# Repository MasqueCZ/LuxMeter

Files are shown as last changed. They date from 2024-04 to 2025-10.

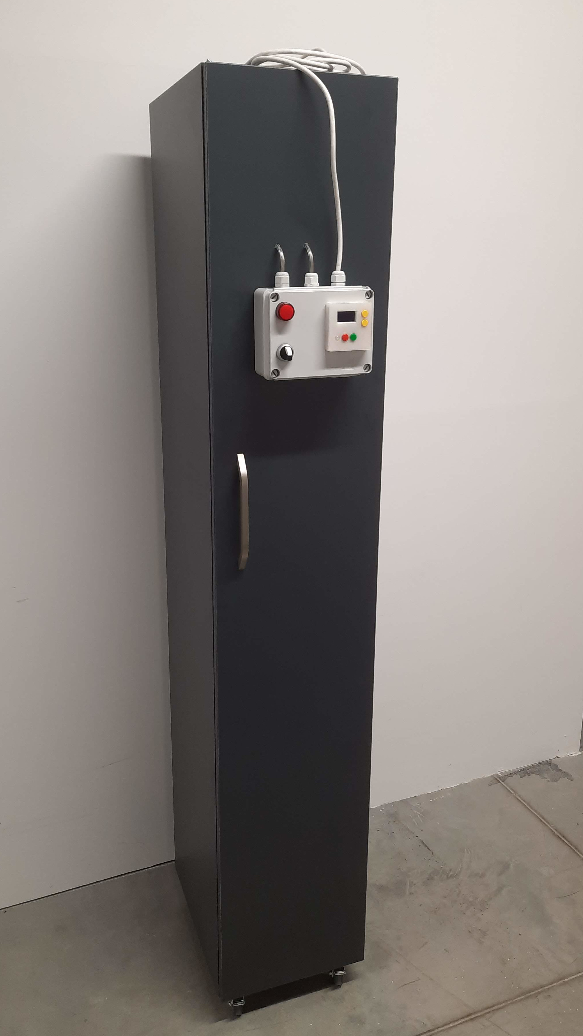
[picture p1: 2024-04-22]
HELPMEfile - MANUAL/Fotky/20240103_172350.jpg

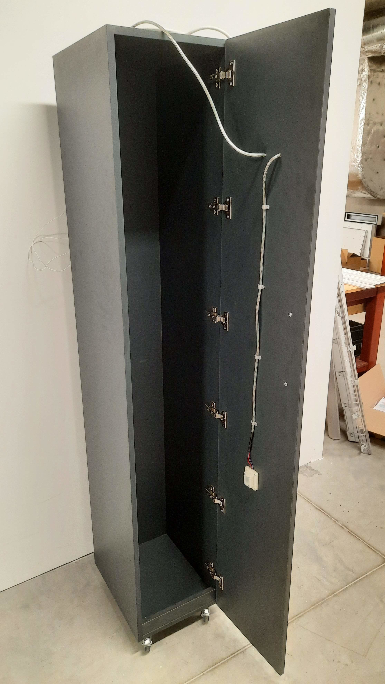
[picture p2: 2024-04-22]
HELPMEfile - MANUAL/Fotky/20240103_172510.jpg

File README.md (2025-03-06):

# LuxMeter
microPython - RPiPico LuxMeter with RTC and SSR relay

My first project, be gentle with comments, but I am open to improvements.

Main part of the project was to measure lumen(light) data over time, save them and then use spreadsheets to analyze the result.
But as clever workers are expensive, I was forced to make different programs, which are tailor made just for one type of 
luminaire and at the end of the measurement, you have result in GREEN or RED light and small text file with important 
milestones of corridor function. (for more detailed info about corridor function see blueprints/scheme.jpg)

But as universal measurement was the main pillar of the project, it is updated the most. And it is now in the list of 
programs under name 00_uni_uni.py.

# uni_uni
You can select sampling time from values 1, 5, 10, 30, 60, 600 and 3600 seconds and the measurement can end at selected 
time of 0, 1, 2, 4, 8, 12, 24, 168 hours. It measures indefinitely if zero is selected.

There is data saver feature which stops saving data after 2 same measurements the 3rd is just "stable" and it continues 
to measure but does not take up another space unless the value changes.

There is also a SSR relay that turns on the power at the start of the measurement, second relay can be turned temporarily
by pushing buttons UP and DOWN at the same time. It can be used to re-start the corridor function cycle or jumpstart
emergency mode for certain luminaires, etc.

-work in progress-

1 - I work on 2 level stable checker, one without a tolerance, one with tolerance but I have to polish it since it can 
slowly slide out of tolerance, without the program realising, since it is so slow, changes, that they would be then 
seen as STABLE.

2 - I want to add data write, even if stable and within the tolerance to save data at least once a minute or once a hour 
or a day, if the sampling is lower, then battery dying or power outage could ruin measurement,
even though it already measured for certain time, but the value never changed it is not written to the file, then you never know when it actually stopped.

3 - Keep all notes in English and translate and then delete czech notes and comments

4 - add magnetic sensor to enter special mode?

5 - menu, while choosing a program, if continuous push of a button scroll faster? Jump by 2, 5 or faster?

6 - add memory check at start so it does not begin if there is not enough space to save file??

7 - make .mpy compiled and compressed files to save 40-60% space?

8 - config file in json? instead of .py?

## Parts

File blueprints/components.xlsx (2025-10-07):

Cena komponent | 610 Kč |  |  | + nějaký box - nově bych netiskl celou krabici, ale použil "skladovku" od ABB, elektrikářský box a tiskl menší část jen pro displej a tlačítko.
alternativně | 1051 Kč |  |  | (nemám pořešený software pro displej s jiným řízením, enkodér (otočný knoflík už trochu jo))
KOMPONENTY
Raspberry Pi Pico | 119 Kč | 1 | 119 Kč | https://rpishop.cz/pico/5117-raspberry-pi-pico-0617588405587.html
IIC I2C OLED displej 0,96" 128x64 Bílý | 115 Kč | 1 | 115 Kč | https://dratek.cz/arduino/1569-iic-i2c-oled-display-0-96-128x64-bily.html
Měření intenzity světla BH1750 | 57 Kč | 1 | 57 Kč | https://dratek.cz/arduino/902-mereni-intenzity-svetla-bh1750.html
RTC hodiny reálného času | 61 Kč | 1 | 61 Kč | https://dratek.cz/arduino/842-rtc-hodiny-realneho-casu.html
CR2032 baterie | 20 Kč | 1 | 20 Kč | https://dratek.cz/arduino/1538-lithiova-knoflikova-baterie-westinghouse-cr2032-dl2032-5004lc-e-cr2032-3v.html
Nepájivé pole 400 pinů | 45 Kč | 1 | 45 Kč | https://dratek.cz/arduino/1226-eses-nepajive-pole-400-pinu.html
40 x M-M Dupont kabel, 20 cm | 53 Kč | 1 | 53 Kč | https://dratek.cz/arduino/1063-eses-40-x-m-m-dupont-kabel.html
40 x M-F Dupont kabel 20 cm | 53 Kč | 1 | 53 Kč | https://dratek.cz/arduino/1214-40-x-m-f-dupont-kabel-20-cm.html
RGB LED modul WS2811 | 15 Kč | 1 | 15 Kč | https://dratek.cz/arduino/1192-rgb-led-modul-ws2811.html
SSR Relé Modul 1 kanál 5VDC Low Level | 53 Kč | 1 | 53 Kč | https://dratek.cz/arduino/1346-ssr-rele-modul-1-kanal-5vdc-250vac-omron-g3mb-202p-solid-state-pro-arduino.html
DuPont kolíková lišta rovná 40Pin samec černá | 3 Kč | 1 | 3 Kč | https://dratek.cz/arduino/1331-dupont-40pin-2-54-mm-kolikova-lista-rovna.html
Mikrospínač TC-1212T 12x12x7.3mm SMD PCB DPS | 4 Kč | 4 | 16 Kč | https://dratek.cz/arduino/1180-mikrospinac-tc-1212t-12x12x7.3mm-smd-pcb-dps.html
SSR Relé Modul 2 kanál 5VDC Low Level | 76 Kč | 1 | 76 Kč | https://dratek.cz/arduino/1347-ssr-rele-modul-2-kanaly-5vdc-250vac-omron-g3mb-202p-solid-state-pro-arduino.html
alternativní komponenty na další verze
Mikrospínač TC-1212T 12x12x7.3mm SMD PCB DPS | 4 Kč | 1 | 4 Kč | duplicitně
Rotační enkodér KY-040 s tlačítkem | 36 Kč | 1 | 36 Kč | https://rpishop.cz/tlacitka-spinace/1329-rotacni-enkoder-ky-040-s-tlacitkem.html
SPI OLED displej 1,54" 128x64 Modrý 3,3-5V | 349 Kč | 1 | 349 Kč | https://dratek.cz/arduino/121930-spi-oled-displej-1-54-128x64-modry-3-3-5v.html
SPI Čtečka microSD karet | 24 Kč | 1 | 24 Kč | https://dratek.cz/arduino/993-ctecka-microsd-karet.html
paměťová karta 16 GB již od | 159 Kč | 1 | 159 Kč
 |  | 2 |  | https://dratek.cz/arduino/121748-40-x-m-m-dupont-kabel-40-cm.html
 |  | 2 |  | https://dratek.cz/arduino/121747-40-x-m-f-dupont-kabel-40-cm.html
 |  | 1 |  | https://rpishop.cz/pico/5117-raspberry-pi-pico-0617588405587.html
 |  | ? |  | https://dratek.cz/arduino/121930-spi-oled-displej-1-54-128x64-modry-3-3-5v.html
 |  | 2 |  | https://dratek.cz/arduino/1347-ssr-rele-modul-2-kanaly-5vdc-250vac-omron-g3mb-202p-solid-state-pro-arduino.html
 |  | 2 |  | https://rpishop.cz/tlacitka-spinace/1329-rotacni-enkoder-ky-040-s-tlacitkem.html
 |  | 2 |  | https://dratek.cz/arduino/993-ctecka-microsd-karet.html
 |  | ? | 167 Kč | https://dratek.cz/arduino/122152-iic-i2c-oled-1-3-displej-128x64-modry.html
 |  | 1 | 350 | https://dratek.cz/arduino/7545-cinova-pajka-bezolovnata-100g-sn99-3cu0-7.html
 |  | 1 | 27 | https://dratek.cz/arduino/1223-analogovy-multiplexer-16-kanalu-cd74hc4067.html
 |  | 9 | 67 | https://dratek.cz/arduino/902-mereni-intenzity-svetla-bh1750.html
SSR Relé Modul 2 kanál 5VDC Low Level | 76 Kč | 3 | 228 Kč | https://dratek.cz/arduino/1347-ssr-rele-modul-2-kanaly-5vdc-250vac-omron-g3mb-202p-solid-state-pro-arduino.html
Raspberry Pi Pico 2 W | 209 Kč | 10 | 2090 Kč | https://rpishop.cz/554053/raspberry-pi-pico-2-w
odpor 33k
odpor 10k

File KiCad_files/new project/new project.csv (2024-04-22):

Source: | C:\Users\novak\PycharmProjects\pythonProject_LuxMeter\KiCad_files\new project\new project.kicad_sch
Date: | 24/02/2023 08:26:35
Tool: | Eeschema (7.0.0)
Generator: | C:\Program Files\KiCad\7.0\bin\scripting\plugins/bom_csv_grouped_by_value_with_fp.py
Component Count: | 4
Ref | Qnty | Value | Cmp name | Footprint | Description | Vendor | DNP
D1 | 1 | SMF30A | SMF30A | Diode_SMD:D_SMF | 200W unidirectional Transil Transient Voltage Suppressor, 30Vrwm, SMF
D2 | 1 | 1.5KExxA | 1.5KExxA | Diode_THT:D_DO-201AE_P15.24mm_Horizontal | 1500W unidirectional TRANSZORB® Transient Voltage Suppressor, DO-201AE
SW1 | 1 | SW_DIP_x04 | SW_DIP_x04 |  | 4x DIP Switch, Single Pole Single Throw (SPST) switch, small symbol
U1 | 1 | RP2040 | RP2040 | Package_DFN_QFN:QFN-56-1EP_7x7mm_P0.4mm_EP3.2x3.2mm | A microcontroller by Raspberry Pi

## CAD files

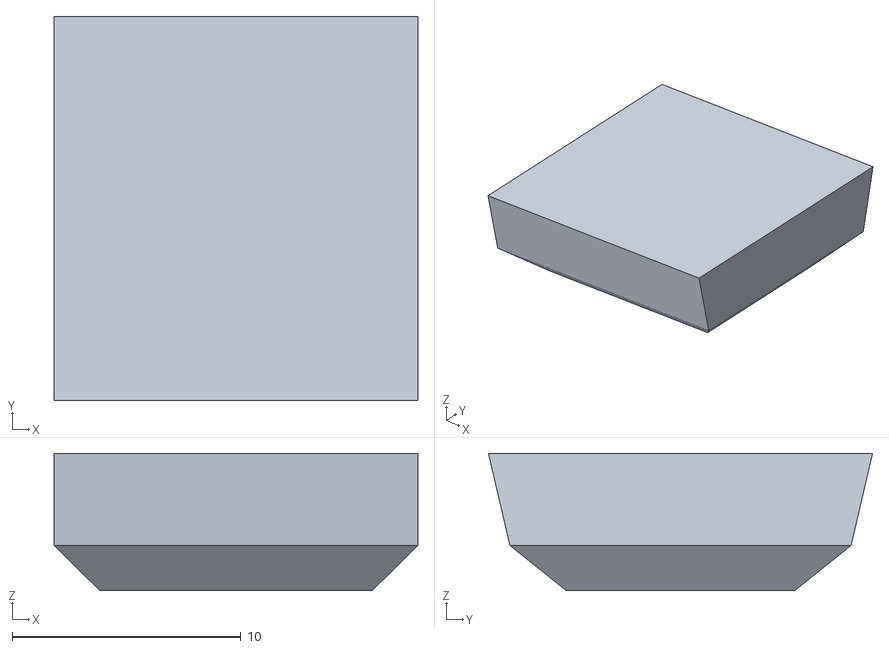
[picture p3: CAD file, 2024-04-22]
3DPRINT/WINDOW-door V0.2.stl
15.9 x 16.8 x 6.00

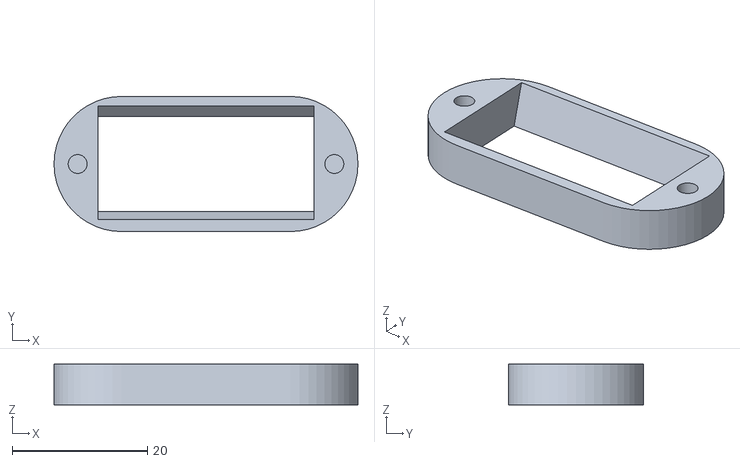
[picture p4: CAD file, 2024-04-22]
3DPRINT/WINDOW V0.2.stl
45.0 x 20.0 x 6.00

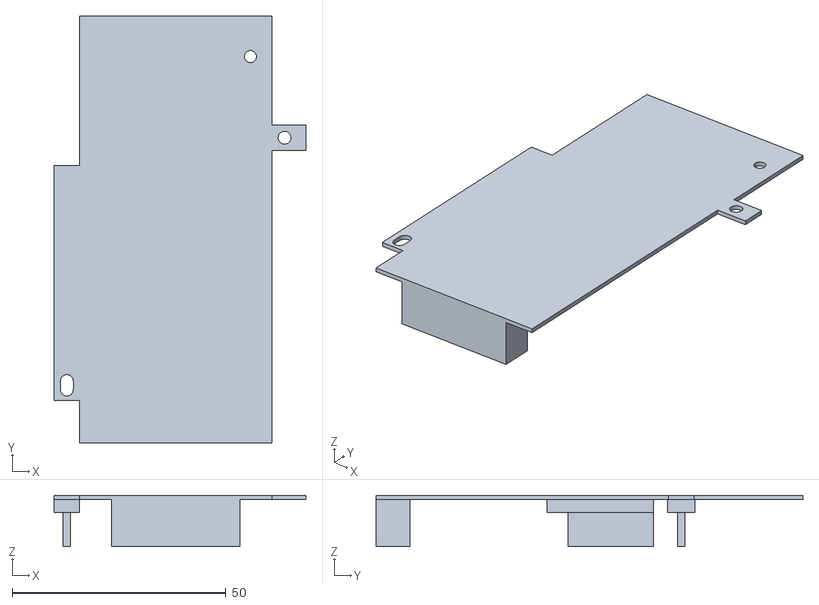
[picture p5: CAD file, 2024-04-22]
3DPRINT/BREADBOARD BED.stl
59.0 x 100.0 x 12.0

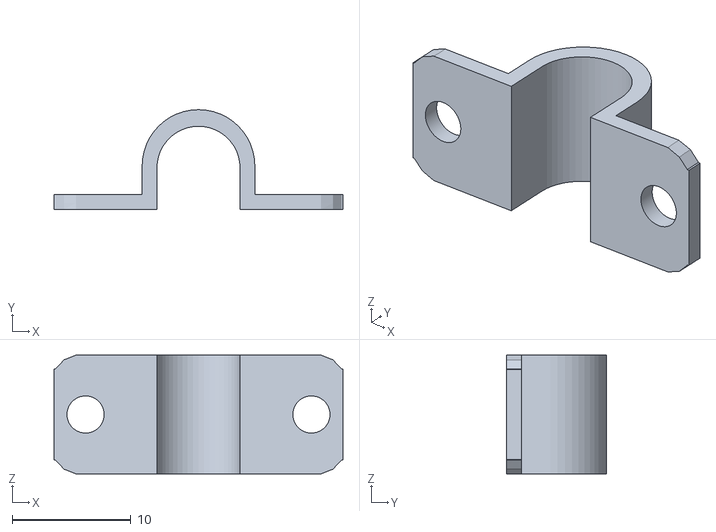
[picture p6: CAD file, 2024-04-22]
3DPRINT/drzak kabelu1.stl
24.4 x 8.41 x 10.0

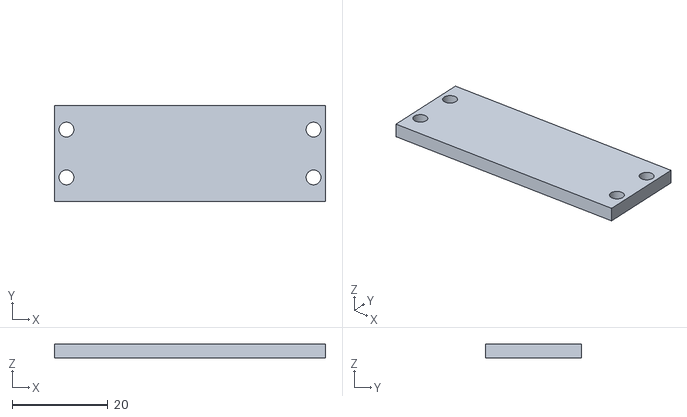
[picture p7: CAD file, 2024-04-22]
3DPRINT/BUTT HOLDER.stl
56.7 x 20.0 x 3.00

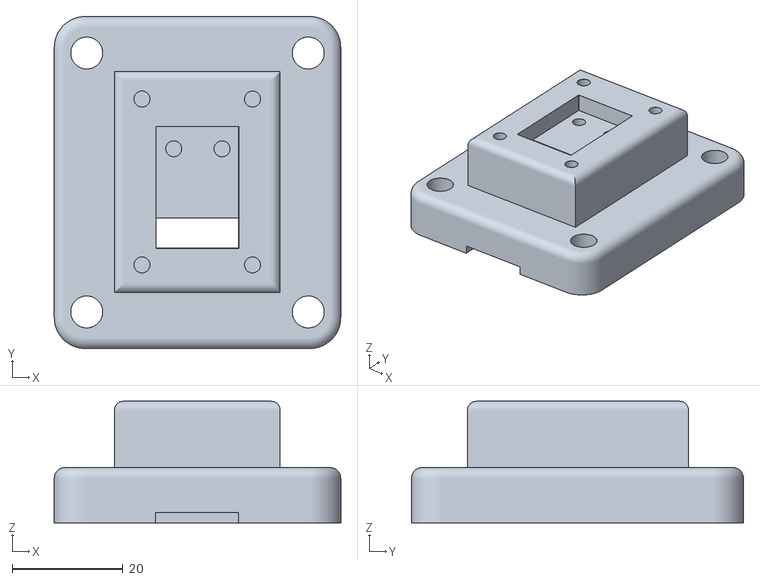
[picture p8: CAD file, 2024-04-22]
3DPRINT/2022_04_26_LUX METER BOX SNS case V.XYZ01.stl
51.8 x 60.1 x 22.0

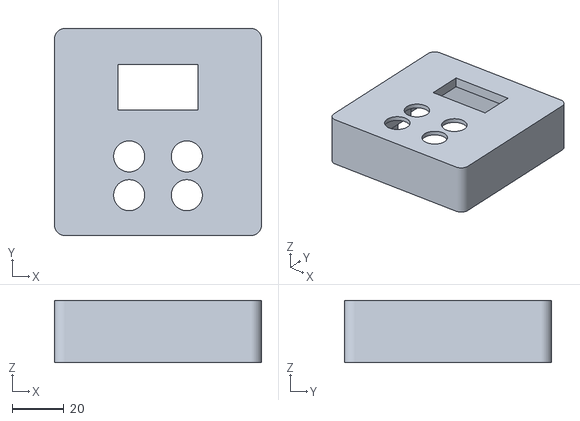
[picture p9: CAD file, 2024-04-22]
3DPRINT/DSP 1.3 and new buttons v04.stl
80.0 x 80.0 x 24.0

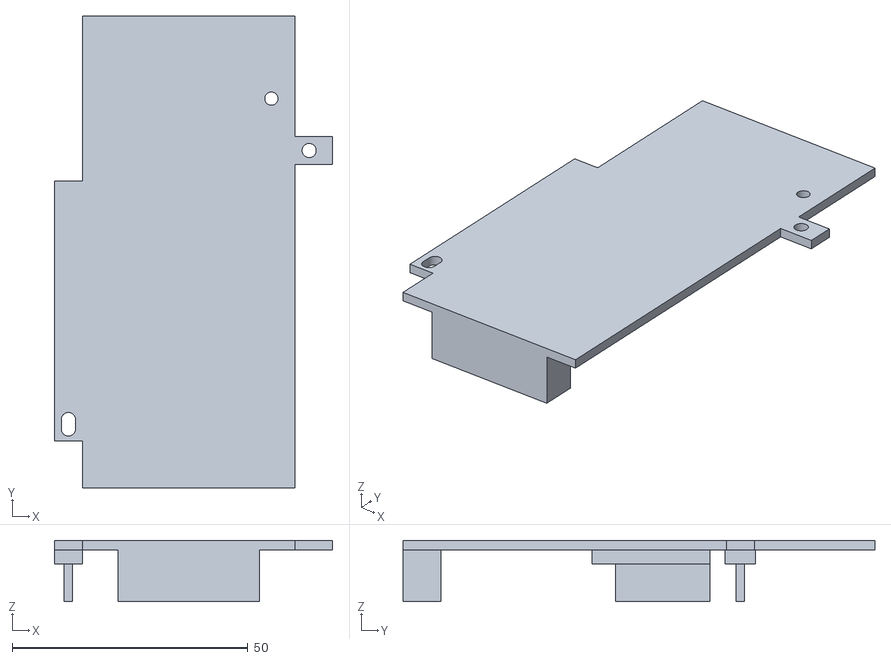
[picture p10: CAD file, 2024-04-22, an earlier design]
3DPRINT/old/test-test-basic box - breadboard BED V0.2.stl
59.0 x 100.0 x 13.0

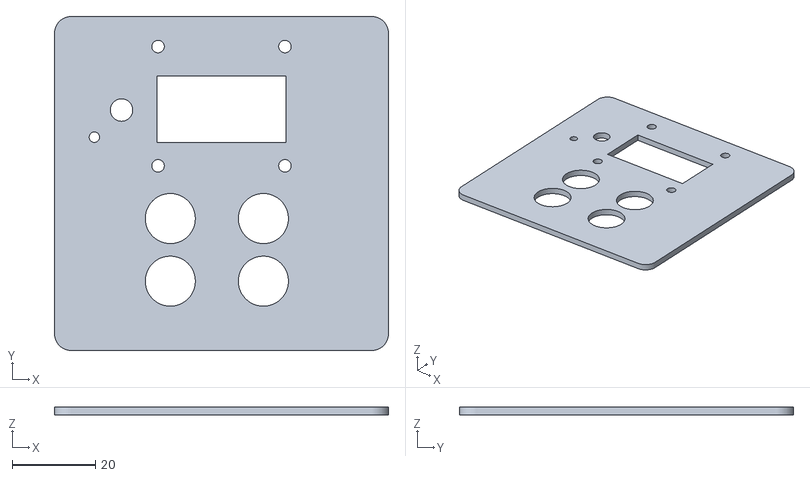
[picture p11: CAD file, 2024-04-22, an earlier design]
3DPRINT/old/test pro novou 1.stl
80.0 x 80.0 x 2.00

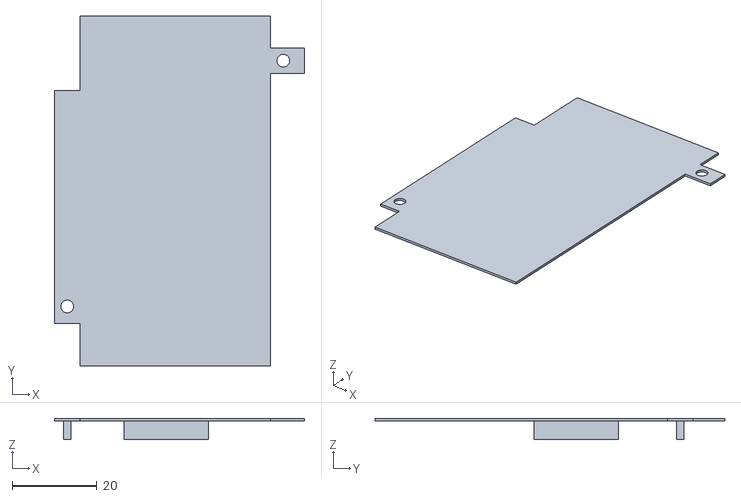
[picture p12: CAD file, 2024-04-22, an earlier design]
3DPRINT/old/test-test-basic box - breadboard BED V0.1.stl
59.0 x 82.5 x 5.00

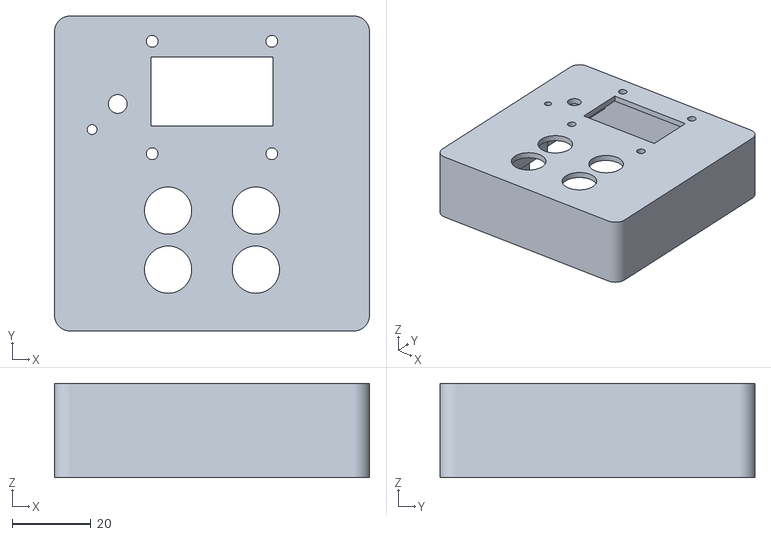
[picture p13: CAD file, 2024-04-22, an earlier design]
3DPRINT/old/test pro novou 3.stl
80.0 x 80.0 x 24.0

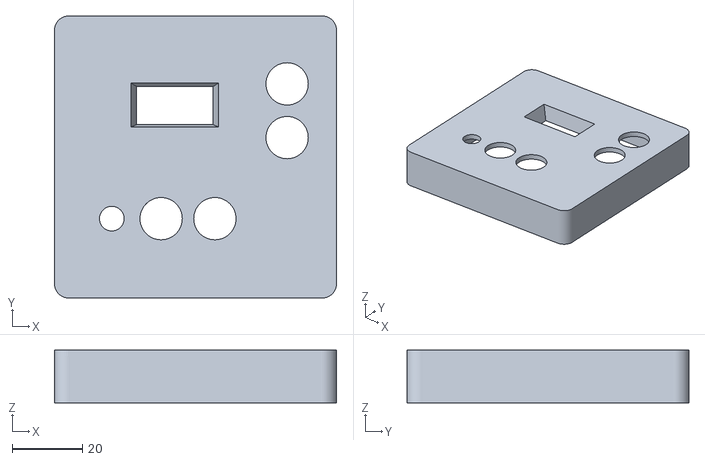
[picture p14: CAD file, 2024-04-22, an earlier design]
3DPRINT/old/test-test-basic box - buttons and all V1.00.stl
80.0 x 80.0 x 15.0

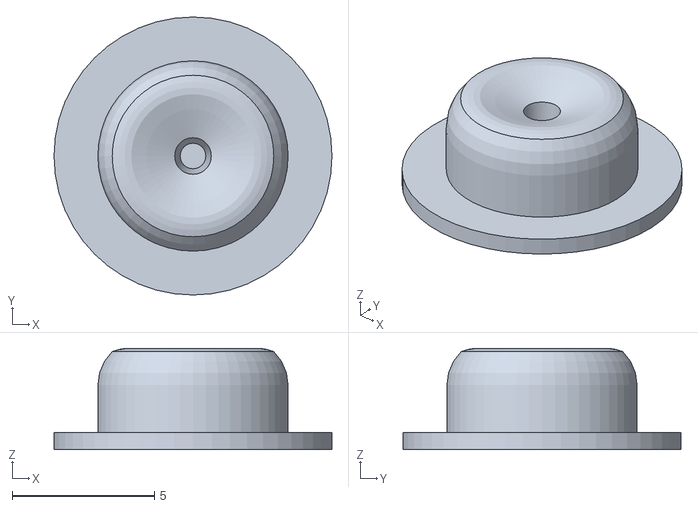
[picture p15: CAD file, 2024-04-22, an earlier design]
3DPRINT/old/BOX - LED COVER.stl
9.78 x 9.78 x 3.56

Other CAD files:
3DPRINT/old/DSP 1.3 and new buttons v01.stl
3DPRINT/old/test pro novou 2.stl
3DPRINT/old/DSP 1.3 and new buttons v03.stl
3DPRINT/old/2022_04_26_LUX METER BOX SNS case V.XYZ.stl
3DPRINT/old/DSP 1.3 and new buttons v02.stl
3DPRINT/2022_04_26_LUX METER BOX SNS case V.XYZ.blend
3DPRINT/basic box - buttons and all.blend
3DPRINT/drzak kabelu.blend
3DPRINT/old/2022_04_26_LUX METER BOX.blend
3DPRINT/old/basic box - buttons and all.blend

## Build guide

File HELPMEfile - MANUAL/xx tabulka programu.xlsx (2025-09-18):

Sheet: List1
body pro vyplneni a postupne se bude "filtrovat seznam" mereni a když bude prazdne, tak tlacitko zalozit a pripravil by se novy program a cislo? + fajfka jestli je k tomu uz vytvoreny testovaci program?
Ty modré texty musí zákazník/obchodník definovat. Jinak si to akorát můžeme domýšlet.

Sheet: Sheet1
aktuální na: | C:\TREVOS\02_Vyrobni_usek\04_Montaze 5260\10_programování driveru |  |  | odkaz nefunguje(soubor xlsx tam není vidět)..nevím proč, ale WIN a PDM se asi nemají rádi
Program č. 1 | FIN:0.7s, RON:120s/100%, FOUT:32s, ABL:10%, SOFF:/ | FIN | 0.7s | RON | 120s/100% | FOUT | 32s | ABL | 10% | SOFF | / | 0.7s 120s/100% 32s 10% /
Program č. 2 | FIN:0.7s, RON:150s/100%, FOUT:30s, ABL:10%, SOFF:/ | FIN | 0.7s | RON | 150s/100% | FOUT | 30s | ABL | 10% | SOFF | / | 0.7s 150s/100% 30s 10% /
Program č. 3 | FIN:0.7s, RON:150s/72%, FOUT:30s, ABL:10%, SOFF:/ | FIN | 0.7s | RON | 150s/72% | FOUT | 30s | ABL | 10% | SOFF | / | 0.7s 150s/72% 30s 10% /
Program č. 4 | FIN:0.7s, RON:150s/100%, FOUT:32s, ABL:10%, SOFF:/ | FIN | 0.7s | RON | 150s/100% | FOUT | 32s | ABL | 10% | SOFF | / | 0.7s 150s/100% 32s 10% / | REGENT
Program č. 5 | FIN:0.7s, RON:120s/100%, FOUT:30s, ABL:10%, SOFF:/ | FIN | 0.7s | RON | 120s/100% | FOUT | 30s | ABL | 10% | SOFF | / | 0.7s 120s/100% 30s 10% /
Program č. 6 | FIN:0.7s, RON:300s/100%, FOUT:32s, ABL:30%, SOFF:/ | FIN | 0.7s | RON | 300s/100% | FOUT | 32s | ABL | 30% | SOFF | / | 0.7s 300s/100% 32s 30% /
Program č. 7 | FIN:0.7s, RON:0s/100%, FOUT:180s, ABL:20%, SOFF:1200s | FIN | 0.7s | RON | 0s/100% | FOUT | 180s | ABL | 20% | SOFF | 1200s | 0.7s 0s/100% 180s 20% 1200s
Program č. 8 | FIN:2s, RON:600s/100%, FOUT:120s, ABL:10%, SOFF:600s | FIN | 2s | RON | 600s/100% | FOUT | 120s | ABL | 10% | SOFF | 600s | 2s 600s/100% 120s 10% 600s
Program č. 9 | FIN:2s, RON:300s/100%, FOUT:120s, ABL:5%, SOFF:/ | FIN | 2s | RON | 300s/100% | FOUT | 120s | ABL | 5% | SOFF | / | 2s 300s/100% 120s 5% /
Program č. 10 | FIN:0.7s, RON:300s/100%, FOUT:32s, ABL:10%, SOFF:/ | FIN | 0.7s | RON | 300s/100% | FOUT | 32s | ABL | 10% | SOFF | / | 0.7s 300s/100% 32s 10% /
Program č. 11 | FIN:0.7s, RON:0s/100%, FOUT:16s, ABL:10%, SOFF:180s | FIN | 0.7s | RON | 0s/100% | FOUT | 16s | ABL | 10% | SOFF | 180s | 0.7s 0s/100% 16s 10% 180s
Program č. 12 | FIN:0.7s, RON:270s/100%, FOUT:32s, ABL:10%, SOFF:600s | FIN | 0.7s | RON | 270s/100% | FOUT | 32s | ABL | 10% | SOFF | 600s | 0.7s 270s/100% 32s 10% 600s
Program č. 13 | FIN:0.7s, RON:30s/100%, FOUT:32s, ABL:20%, SOFF:/ | FIN | 0.7s | RON | 30s/100% | FOUT | 32s | ABL | 20% | SOFF | / | 0.7s 30s/100% 32s 20% /
Program č. 14 | FIN:0.7s, RON:60s/100%, FOUT:30s, ABL:30%, SOFF:/ | FIN | 0.7s | RON | 60s/100% | FOUT | 30s | ABL | 30% | SOFF | / | 0.7s 60s/100% 30s 30% /
Program č. 15 | FIN:0.7s, RON:300s/100%, FOUT:60s, ABL:10%, SOFF:/ | FIN | 0.7s | RON | 300s/100% | FOUT | 60s | ABL | 10% | SOFF | / | 0.7s 300s/100% 60s 10% /
Program č. 16 | FIN:0.7s, RON:900s/100%, FOUT:30s, ABL:15%, SOFF:/ | FIN | 0.7s | RON | 900s/100% | FOUT | 30s | ABL | 15% | SOFF | / | 0.7s 900s/100% 30s 15% /
Program č. 17 | FIN:0.7s, RON:32s/100%, FOUT:32s, ABL:10%, SOFF:/ | FIN | 0.7s | RON | 32s/100% | FOUT | 32s | ABL | 10% | SOFF | / | 0.7s 32s/100% 32s 10% /
Program č. 18 | FIN:0.7s, RON:120s/100%, FOUT:32s, ABL:15%, SOFF:/ | FIN | 0.7s | RON | 120s/100% | FOUT | 32s | ABL | 15% | SOFF | / | 0.7s 120s/100% 32s 15% /
Program č. 19 | FIN:0.7s, RON:300s/100%, FOUT:90s, ABL:10%, SOFF:300s | FIN | 0.7s | RON | 300s/100% | FOUT | 90s | ABL | 10% | SOFF | 300s | 0.7s 300s/100% 90s 10% 300s
Program č. 20 | FIN:0.7s, RON:180s/100%, FOUT:32s, ABL:10%, SOFF:120s | FIN | 0.7s | RON | 180s/100% | FOUT | 32s | ABL | 10% | SOFF | 120s | 0.7s 180s/100% 32s 10% 120s
Program č. 21 | FIN:0.7s, RON:180s/100%, FOUT:32s, ABL:15%, SOFF:/ | FIN | 0.7s | RON | 180s/100% | FOUT | 32s | ABL | 15% | SOFF | / | 0.7s 180s/100% 32s 15% /
Program č. 22 | FIN:0.7s, RON:180s/100%, FOUT:32s, ABL:10%, SOFF:/ | FIN | 0.7s | RON | 180s/100% | FOUT | 32s | ABL | 10% | SOFF | / | 0.7s 180s/100% 32s 10% /
Program č. 23 | FIN:5s, RON:180s/100%, FOUT:32s, ABL:10%, SOFF:/ | FIN | 5s | RON | 180s/100% | FOUT | 32s | ABL | 10% | SOFF | / | 5s 180s/100% 32s 10% /
Program č. 24 | FIN:0.7s, RON:300s/80%, FOUT:32s, ABL:20%, SOFF:/ | FIN | 0.7s | RON | 300s/80% | FOUT | 32s | ABL | 20% | SOFF | / | 0.7s 300s/80% 32s 20% /
Program č. 25 | FIN:0.7s, RON:300s/100%, FOUT:32s, ABL:10%, SOFF:7200s | FIN | 0.7s | RON | 300s/100% | FOUT | 32s | ABL | 10% | SOFF | 7200s | 0.7s 300s/100% 32s 10% 7200s
Program č. 26 | FIN:0.7s, RON:300s/100%, FOUT:32s, ABL:10%, SOFF:1800s | FIN | 0.7s | RON | 300s/100% | FOUT | 32s | ABL | 10% | SOFF | 1800s | 0.7s 300s/100% 32s 10% 1800s
Program č. 27 | FIN:0.7s, RON:120s/100%, FOUT:32s, ABL:0%, SOFF:/ | FIN | 0.7s | RON | 120s/100% | FOUT | 32s | ABL | 0% | SOFF | 0s | 0.7s 120s/100% 32s 0% 0s | REGENT
Program č. 28 | FIN:5s, RON:300s/100%, FOUT:32s, ABL:10%, SOFF:/ | FIN | 5.0s | RON | 300s/100% | FOUT | 32s | ABL | 10% | SOFF | / | 5.0s 300s/100% 32s 10% /
Program č. 29 | FIN:0.7s, RON:60s/100%, FOUT:2s, ABL:10%, SOFF:1800s | FIN | 0.7s, | RON | 60s/100%, | FOUT | 2s, | ABL | 10% | SOFF | 1800s | 0.7s, 60s/100%, 2s, 10% 1800s
Program č. 30 | FIN:0.7s, RON:300s/100%, FOUT:1s, ABL:30%, SOFF:/ | FIN | 0.7s | RON | 300s/100% | FOUT | 1s | ABL | 30% | SOFF | / | 0.7s 300s/100% 1s 30% /
Program č. 31 | FIN:5s, RON:600s/100%, FOUT:32s, ABL:10%, SOFF:/ | FIN | 5s | RON | 600s/100% | FOUT | 32s | ABL | 10% | SOFF | / | 5s 600s/100% 32s 10% /
Program č. 32 | FIN:0.7s, RON:120s/100%, FOUT:32s, ABL:20%, SOFF:/ | FIN | 0.7s | RON | 120s/100% | FOUT | 32s | ABL | 20% | SOFF | / | 0.7s 120s/100% 32s 20% /
 |  |  |  |  |  |  |  |  |  |  |  | 0%
 |  |  |  |  |  |  |  |  |  |  |  | 0%
 |  |  |  |  |  |  |  |  |  |  |  | 0%
 |  |  |  |  |  |  |  |  |  |  |  | 0%
 |  |  |  |  |  |  |  |  |  |  |  | 0%
 |  |  |  |  |  |  |  |  |  |  |  | 0%

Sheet: Sheet2
55171007000011 | OSRAM programovaný driver | OSRAM OTi DALI 35/220-240/400 D NFC FL programovaný driver pro ARGON, CORRIDOR P15, FIN:0.7s, RON:300s/100%, FOUT:60s, ABL:10%, SOFF:/, Iset:300mA | 274.7641 | 0 | 0 | 0 | Programované drivery | 0 | osram | 2024-03-27 10:14 | 21 | [Kusovník zkontrolován, Postup zkontrolován, Zboží zkontrolováno, Výrobní kód doplněn] | [Obsaženo v kusovníku, Má kusovník, Má postup, Má kalkulační ceny] | 80.10.01 | Dresler Jan |  | 2023-12-07 08:02 | 14 | 0 | 0 | 0 | 274.7641 | 0 | Ne
55171007000015 | OSRAM programovaný driver | OSRAM OTi DALI 35/220-240/400 D NFC FL programovaný driver pro ARGON, CORRIDOR P34, FIN:0.7s, RON:60s/100%, FOUT:60s, ABL:10%, SOFF:1800s, Iset:250mA | 258.0741 | 0 | 0 | 0 | Programované drivery | 0 | osram | 2025-02-24 12:52 | 21 | [Kusovník zkontrolován, Postup zkontrolován, Zboží zkontrolováno, Výrobní kód doplněn] | [Obsaženo v kusovníku, Má kusovník, Má postup, Má kalkulační ceny] | 80.10.01 | Dresler Jan |  | 2025-02-24 10:50 | 14 | 0 | 0 | 0 | 258.0741 | 0 | Ne
55628007000001 | OSRAM programovaný driver | OSRAM OTi DALI 35/220-240/400 D NFC FL programovaný driver pro EcoBility, CORRIDOR P25, FIN:0.7s, RON:300s/100%, FOUT:32s, ABL:10%, SOFF:7200s(2hod), Iset:300mA | 274.7641 | 0 | 0 | 0 | Programované drivery | 0 | osram | 2024-06-11 13:30 | 21 | [Kusovník zkontrolován, Postup zkontrolován, Zboží zkontrolováno, Výrobní kód doplněn] | [Obsaženo v kusovníku, Má kusovník, Má postup, Má kalkulační ceny] | 80.10.01 | Dresler Jan |  | 2024-05-06 08:30 | 14 | 0 | 0 | 0 | 274.7641 | 0 | Ne
55628007000004 | OSRAM programovaný driver | OSRAM OTi DALI 35/220-240/400 D NFC FL programovaný driver pro EcoBility, CORRIDOR P26, FIN:0.7s, RON:300s/100%, FOUT:32s, ABL:10%, SOFF:1800s(0,5hod), Iset:300mA | 274.7641 | 0 | 0 | 0 | Programované drivery | 0 | osram | 2024-06-14 10:21 | 21 | [Kusovník zkontrolován, Postup zkontrolován, Zboží zkontrolováno, Výrobní kód doplněn] | [Obsaženo v kusovníku, Má kusovník, Má postup, Má kalkulační ceny] | 80.10.01 | Dresler Jan |  | 2024-06-11 13:31 | 14 | 0 | 0 | 0 | 274.7641 | 0 | Ne
55155007000005 | OSRAM programovaný driver | OSRAM OTi DALI 35/220-240/400 D NFC FL programovaný driver pro Enerdominio, CORRIDOR P6, FIN:0.7s, RON:300s/100%, FOUT:32s, ABL:30%, SOFF:/, Iset:300mA | 274.7641 | 0 | 0 | 0 | Programované drivery | 0.2051 | osram | 2024-01-11 12:45 | 21 | [Kusovník zkontrolován, Postup zkontrolován, Zboží zkontrolováno, Výrobní kód doplněn] | [Obsaženo v kusovníku, Má kusovník, Má postup, Má kalkulační ceny] | 80.10.01 | Dresler Jan |  |  | 14 | 0 | 0 | 0 | 274.7641 |  | Ne
55155007000004 | OSRAM programovaný driver | OSRAM OTi DALI 35/220-240/400 D NFC FL programovaný driver pro Enerdominio, CORRIDOR P6, FIN:0.7s, RON:300s/100%, FOUT:32s, ABL:30%, SOFF:/, Iset:350mA | 274.7641 |  |  |  | Programované drivery | 0.2051 | osram | 2024-01-11 12:45 | 21 | [Kusovník zkontrolován, Postup zkontrolován, Zboží zkontrolováno, Výrobní kód doplněn] | [Má kusovník, Má postup, Má kalkulační ceny] | 80.10.01 | Dresler Jan |  |  | 14 | 0 | 0 | 0 | 274.7641 |  | Ne
55073007000002 | OSRAM programovaný driver | OSRAM OTi DALI 35/220-240/400 D NFC FL programovaný driver pro ESSE-CI, CORRIDOR P22, FIN:0.7s, RON:180s/100%, FOUT:32s, ABL:10%, SOFF:/, Iset:300mA | 274.7641 |  |  |  | Programované drivery | 0.2051 | osram | 2024-05-27 14:21 | 21 | [Kusovník zkontrolován, Postup zkontrolován, Zboží zkontrolováno, Výrobní kód doplněn] | [Má kusovník, Má postup, Má kalkulační ceny] | 80.10.01 | Dresler Jan |  |  | 14 | 0 | 0 | 0 | 274.7641 |  | Ne
55247007000010 | OSRAM programovaný driver | OSRAM OTi DALI 35/220-240/400 D NFC FL programovaný driver pro firmu Regent, CORRIDOR P27, FIN:0.7s, RON:120s/100%, FOUT:32s, ABL:0%, SOFF:0s, Iset:300mA | 274.7641 |  |  |  | Programované drivery | 0.2051 | osram | 2024-06-14 10:23 | 21 | [Kusovník zkontrolován, Postup zkontrolován, Zboží zkontrolováno, Výrobní kód doplněn] | [Má kusovník, Má postup, Má kalkulační ceny] | 80.10.01 | Dresler Jan |  |  | 14 | 0 | 0 | 0 | 274.7641 |  | Ne
55247007000011 | OSRAM programovaný driver | OSRAM OTi DALI 35/220-240/400 D NFC FL programovaný driver pro firmu Regent, CORRIDOR P27, FIN:0.7s, RON:120s/100%, FOUT:32s, ABL:0%, SOFF:0s, Iset:350mA | 274.7641 | 0 | 22 | 0 | Programované drivery | 0.2051 | osram | 2024-06-14 10:23 | 21 | [Kusovník zkontrolován, Postup zkontrolován, Zboží zkontrolováno, Výrobní kód doplněn] | [Obsaženo v kusovníku, Má kusovník, Má postup, Má kalkulační ceny] | 80.10.01 | Dresler Jan |  |  | 14 | 0 | 0 | 0 | 274.7641 |  | Ne
55377007000002 | OSRAM programovaný driver | OSRAM OTi DALI 35/220-240/400 D NFC FL programovaný driver pro LIDERLED, CORRIDOR P11, FIN:0.7s, RON:0s/100%, FOUT:16s, ABL:10%, SOFF:180s/0%, Iset:300mA | 274.7641 |  |  |  | Programované drivery | 0.2051 | osram | 2024-01-11 12:49 | 21 | [Kusovník zkontrolován, Postup zkontrolován, Zboží zkontrolováno, Výrobní kód doplněn] | [Má kusovník, Má postup, Má kalkulační ceny] | 80.10.01 | Dresler Jan |  |  | 14 | 0 | 0 | 0 | 274.7641 |  | Ne
55063007000001 | OSRAM programovaný driver | OSRAM OTi DALI 35/220-240/400 D NFC FL programovaný driver pro Prolight, CORRIDOR P10 , FIN:0.7s, RON:300s/100%, FOUT:32s, ABL:10%, SOFF:/, Iset:300mA | 274.7641 | 0 | 0 | 0 | Programované drivery | 0 | osram | 2024-01-11 12:44 | 21 | [Kusovník zkontrolován, Postup zkontrolován, Zboží zkontrolováno, Výrobní kód doplněn] | [Obsaženo v kusovníku, Má kusovník, Má postup, Má kalkulační ceny] | 80.10.01 | Dresler Jan |  | 2023-11-01 06:49 | 14 | 0 | 0 | 0 | 274.7641 | 0 | Ne
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

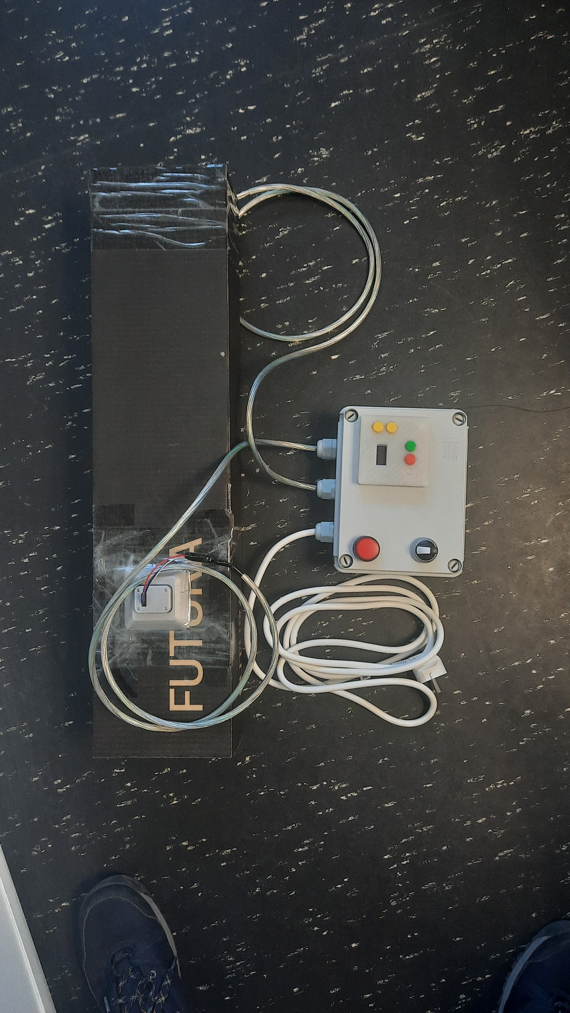
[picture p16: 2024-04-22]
HELPMEfile - MANUAL/Fotky/20230301_140056.jpg

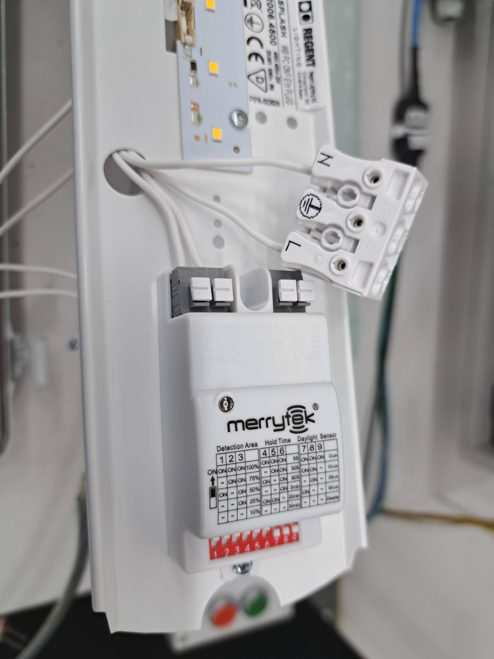
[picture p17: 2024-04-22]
HELPMEfile - MANUAL/Fotky/20240215_122558.jpg

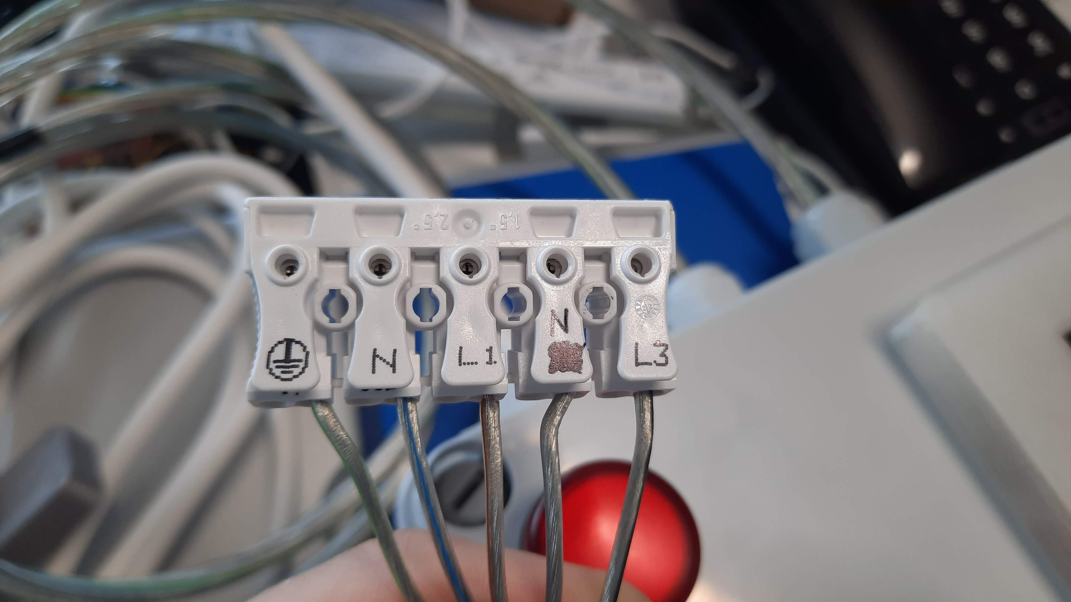
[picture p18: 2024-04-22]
HELPMEfile - MANUAL/Fotky/20230224_143404.jpg

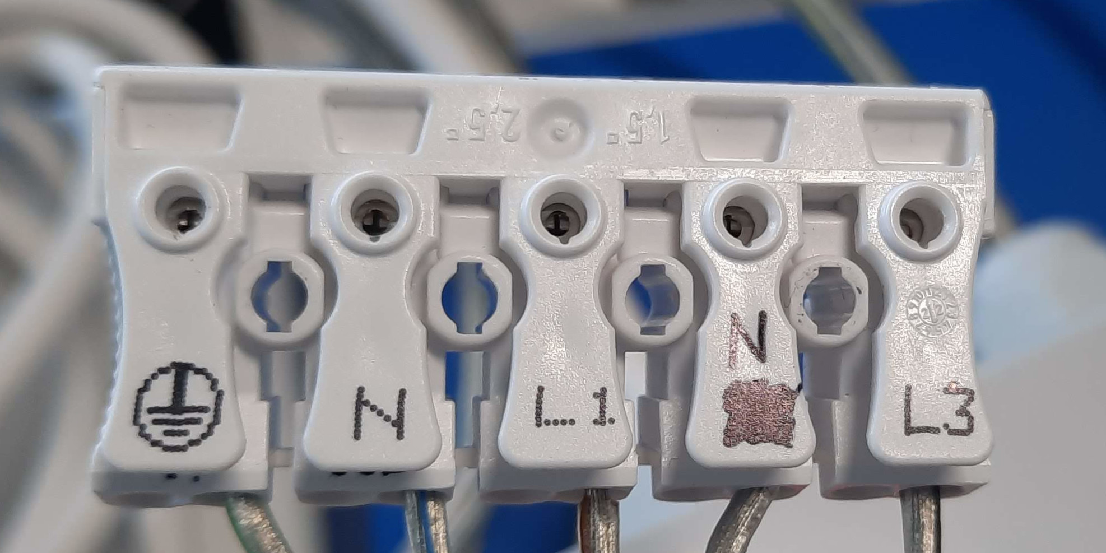
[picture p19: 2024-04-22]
HELPMEfile - MANUAL/edited/20230224_143404.jpg

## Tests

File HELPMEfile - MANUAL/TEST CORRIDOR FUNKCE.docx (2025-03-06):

Vypracoval dne: | Vypr./Přezkoušel dne: 10.11.2022 | Schválil dne: 10.11.2022
Funkce: | Funkce: tp | Funkce:
Jméno: | Jméno: Dresler J. | Jméno: Kulhanek P.
Podpis: | Podpis: | Podpis:

Technologický postup pro testování CORRIDOR funkce.

Funkční kontrola corridor funkce.

1. FUNKČNÍ KONTROLA CORRIDOR FUNKCE - PŘÍPRAVA | provádí/funkce: | Zkušební technik
Seznam pomůcek: | - Přípravek s luxmetrem pro měření corridor funkce včetně napájecího zdroje. - 5Pol svorkovnici k propojení přípravku se svítidlem. - Otočný vypínač pro přivedení napětí 230V na přípravek. - Zatemňovací box.

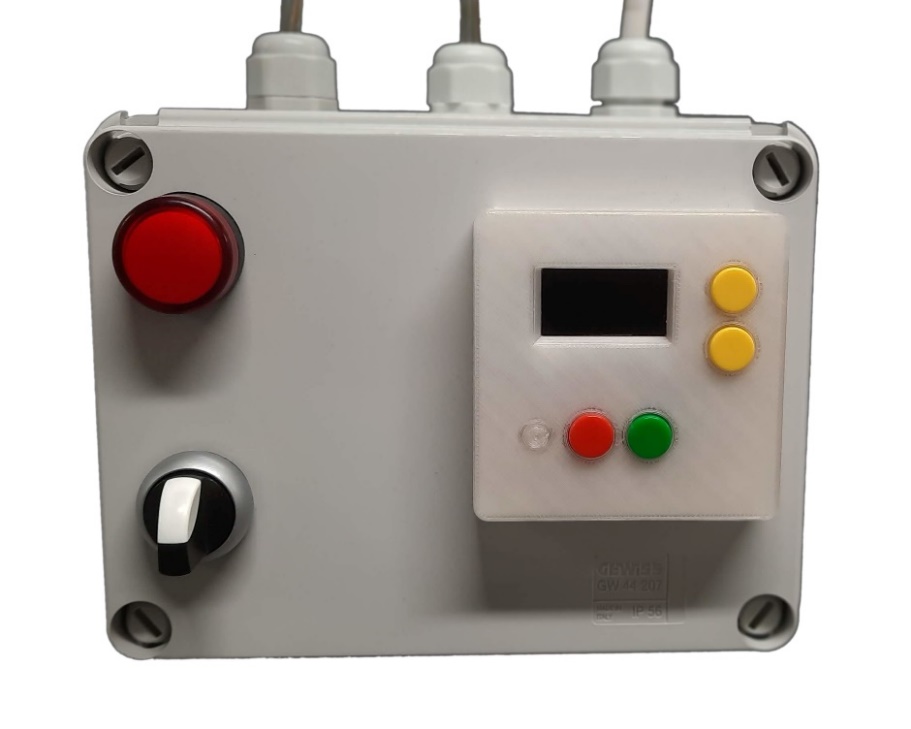
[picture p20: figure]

!

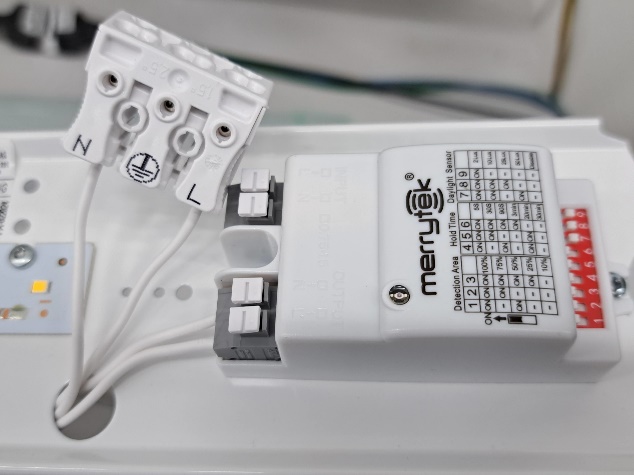
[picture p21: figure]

1. Připojit přípravek k 230V.
2. A) Připojit přípravek ke svítidlu ⏚ N L1 L2(DA/N) a L3 (DA/L) na svorkovnici.

B) Při zapojení SNS MASTER odpojit napájení senzoru a z L a N a zajistit 3P svorkovnicí viz foto, pro správné zpětné zapojení !

C) Při zapojení svítidla s konektorem nutno zapojit ⏚ N L1 L2(DA/N) a L3 (DA/L) přímo na driver. Vodiče si zajistit 5P svorkovnicí, pro správné zpětné zapojení.

3. U svítidel s nouzí Mxh – odpojit baterii.
4. Vložit svítidlo do zatemněného boxu.
5. Zkontrolovat, že je box řádně zavřený.
6. Otočným vypínačem uvést přípravek k provozu. Rozsvítí se červená výstražná kontrolka.
7. Vybrat program pomocí žlutých tlačítek nahoru a dolů. Výběr programu provést dle kusovníku – název produktu driveru. Např. TCI LED driver T-LED 60/80-400 DALI NFC programovaný driver, , CORRIDOR P1, FIN:0.7s, RON:120s/100%, FOUT:32s, ABL:10%, SOFF:/, Iset:300mA
8. Výběr programu potvrdit zeleným tlačítkem přípravku. Na přípravku se rozsvítí žlutá LED.

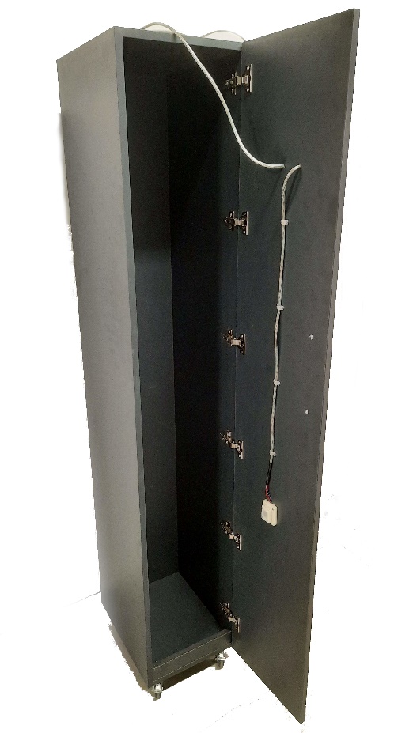
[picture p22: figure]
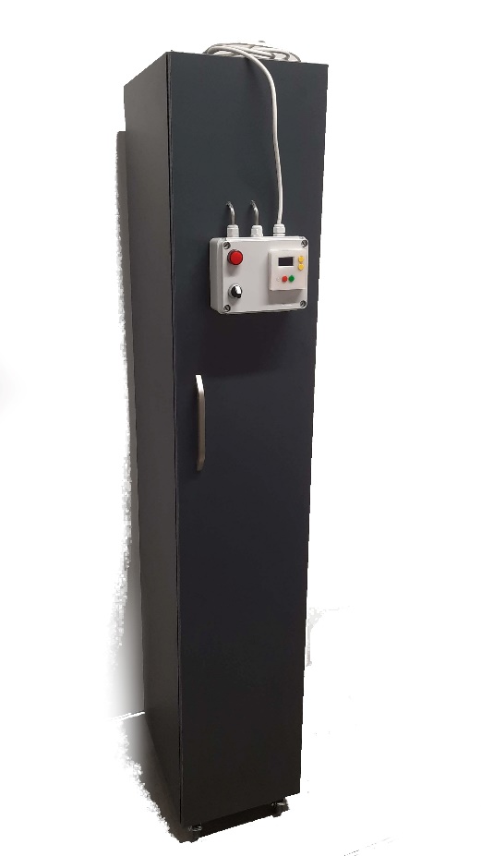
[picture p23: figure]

| 9. Na přípravku stisknout zelené tlačítko. Tím se zahájí test a na přípravku se rozsvítí modrá LED. 10. Vyčkat na dokončení testu. Délka testu je dána nahranou corridor funkcí. 11. Správné otestování je potvrzeno rozsvícením zelené diody na přípravku. V případě rozsvícení rudé diody je test NOK. 12. Po dokončení testu stisknout červené tlačítko. 13. Pro otestování dalšího svítidla otočit vypínačem do stavu vypnuto (zhasne červená kontrolka) a postupovat od bodu 2. tohoto postupu.

ZPĚT

2. PŘESUN DAT Z JEDNOTKY | provádí/funkce: | Zkušební technik

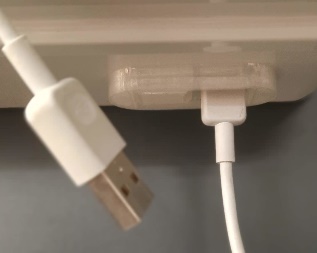
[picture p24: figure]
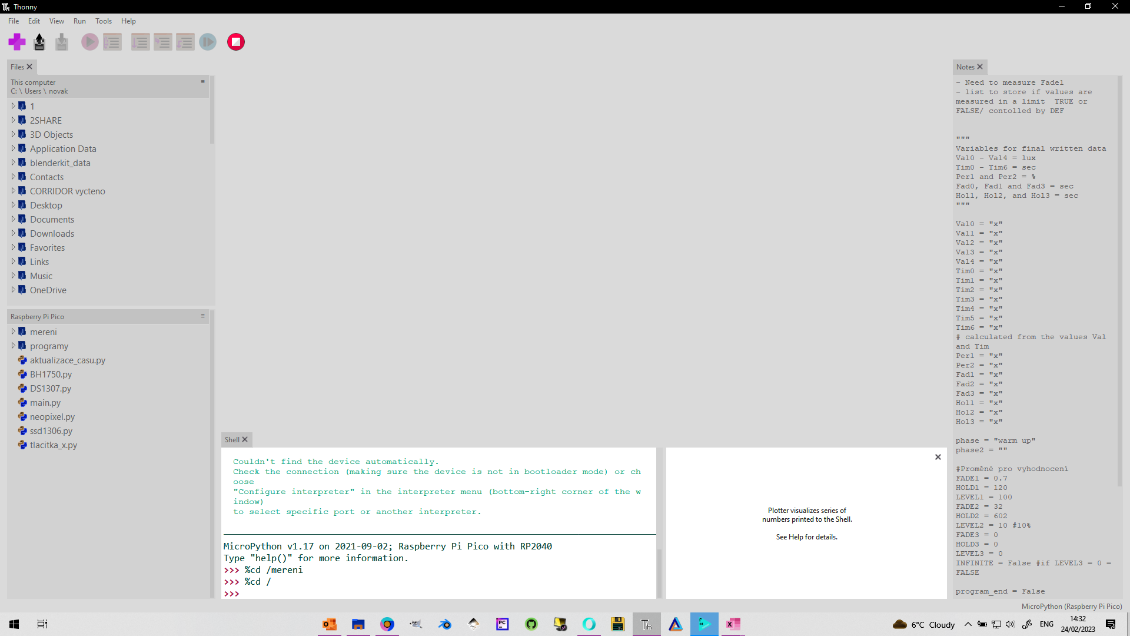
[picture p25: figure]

| 1. Spustit program THONNY. 2. Připojit jednotku k PC kabelem USB. (skrz postranní okénko) 3. Zmáčknout červené tlačítko reset na jednotce. 4. Zmáčkout tlačítko STOP v programu. 5. Mikroprocesor se připojí pod názvem Raspberry Pi Pico – pokud ne, opakovat od kroku č. 3. 6. Otevřít složku měření.

ZPĚT

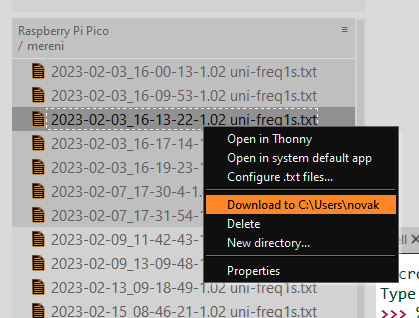
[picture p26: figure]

| 7. Označit programy které chcete zkopírovat. 8. Pravé tlačítko myši a „download to C:\Users\jméno_uživatele“ 9. Ze složky zkopírovat na zálohované místo, do složky pojmenované podle čísla zakázky a podsložky s číslem kódu testovaného svítidla.

ZPĚT

3. VÝSLEDEK MĚŘENÍ | provádí/funkce: | Zkušební technik
Výsledek měření: Program started 09:16:45 2023-07-28 version: v2.5-01-01 FIN:0.7s, RON:120s/100%, FOUT:32s, ABL:10%, SOFF:/ Parameters: Fade 0.7s, Hold 120s at 100% fade 32s, hold 60s at 10% fade 0s, hold 0s at 0% Driver nikdy nevypíná úplně do 0% ale měří jen: 00:04:10 Measurement: Stable at: 0.0lx OK - Fade time 1: -1s OK - Hold time 1: 122s at value: 13940.0lx (100%) OK - Fade time 2: 31s OK - level 2: 12.3% OK - Světlo svítilo dál, ukončeno automaticky po definovaném čase Result:Měření OK | Zde je náhled výsledného měření pro program 01. V případě, že svítí kontrolka po měření červeně, zkontrolovat zapojení, pustit případně znovu. Pak zavolat kvalitu / technickou podporu. V případě, že se program zasekne a neběží dál volejte technické o podporu. Případně zkusit pustit program znovu. Občas v něm „straší“ Tabulka programů: C:\TREVOS\02_Vyrobni_usek\04_Montaze 5260\10_programování driveru

ZPĚT

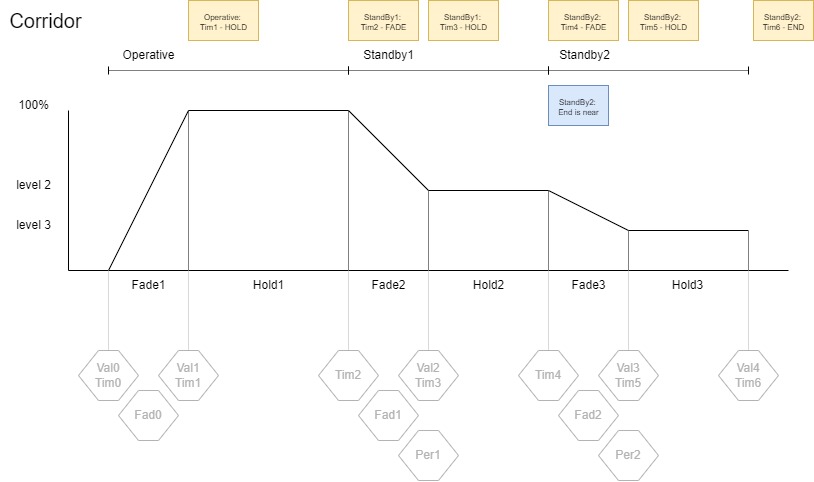
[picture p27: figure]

4. NÁHLED KROKŮ MĚŘÍCÍHO BOXU A FUNKCE CORRIDOR | provádí/funkce: | Zkušební technik

ZPĚT

Jen pro vnitřní potřebu TREVOS a.s. Úložiště : C:\Users\novak\Documents\GitHub\LuxMeter\HELPMEfile - MANUAL\TEST CORRIDOR FUNKCE.docx

TP 170009970009901 TREVOS a.s. Datum tisku : 4.2.2025 Revize : 0 REŽIM DOKUMENTU SE SCHVÁLENÍM strana : 5 z 8

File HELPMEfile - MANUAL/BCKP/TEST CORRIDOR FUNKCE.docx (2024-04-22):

Vypracoval dne: | Vypr./Přezkoušel dne: 04.11.2022 | Schválil dne: 02.11.2022
Funkce: | Funkce: VTPV | Funkce: -
Jméno: | Jméno: Dresler J. | Jméno: -
Podpis: | Podpis: | Podpis:

Technologický postup pro testování CORRIDOR funkce.

Funkční kontrola corridor funkce.

1. FUNKČNÍ KONTROLA CORRIDOR FUNKCE - PŘÍPRAVA | provádí/funkce: | Zkušební technik
Seznam pomůcek: | - Přípravek s luxmetrem pro měření corridor funkce včetně napájecího zdroje 5V a USB kabelu. - 5Pol svorkovnici k propojení přípravku se svítidlem. - Kolébkový vypínač pro přivedení napětí 230V na přípravek. - Zatemňovací box.

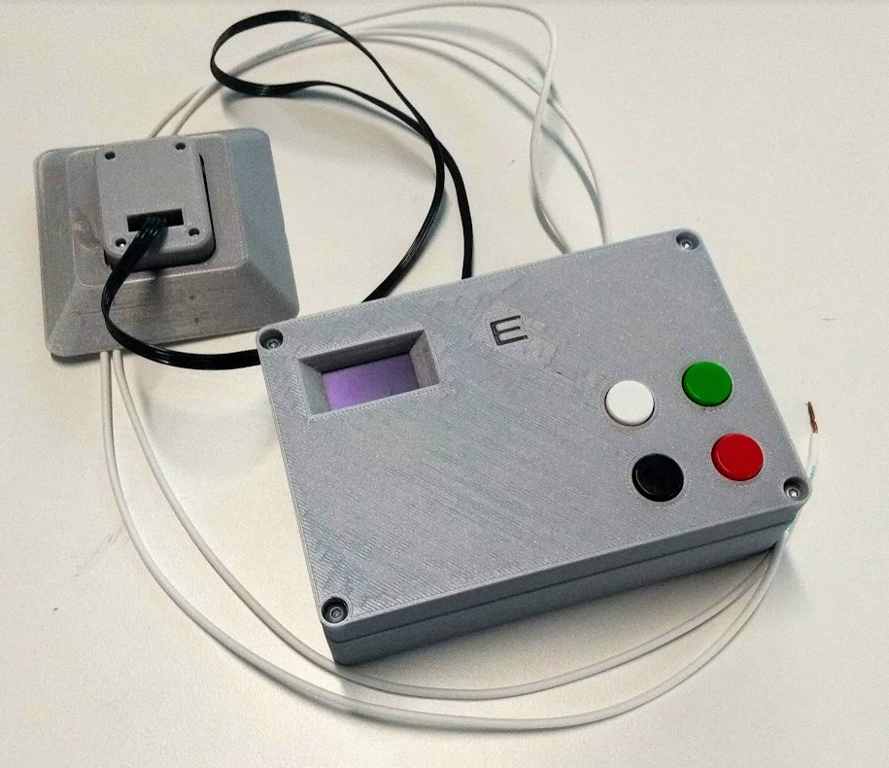
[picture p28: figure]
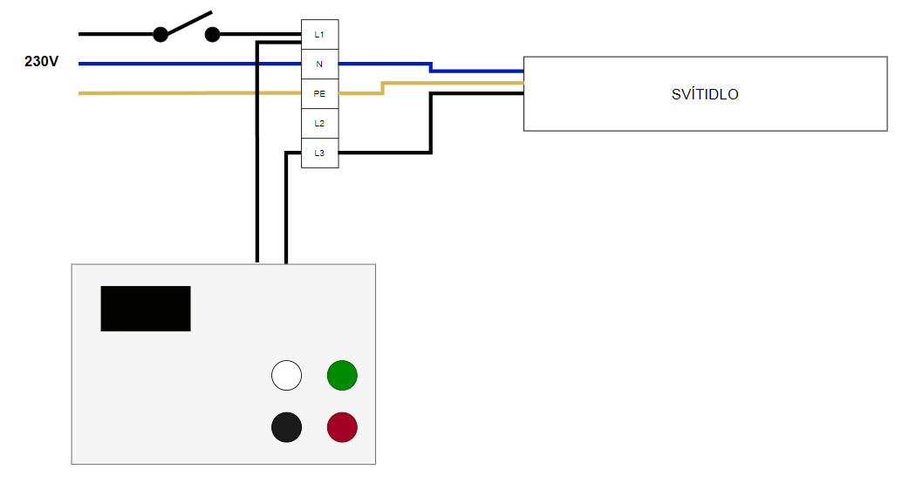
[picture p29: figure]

| 1. Připojit zdroj 5V k přípravku. 2. Připojit přípravek ke svítidlu dle schéma zapojení. 3. Vybrat program pomocí bílého a černého tlačítka. Výběr programu provést dle tabulky variant (TABULKA VARIANT). Každý program testuje daný průběh CORRIDOR funkce. 4. Výběr programu potvrdit zeleným tlačítkem přípravku. Na přípravku se rozsvítí žlutá LED.


| 5. Vložit svítidlo z boku do zatemněného boxu. 6. Přepnout vypínač a přivést 230V do přípravku. 7. Na přípravku stisknou zelené tlačítko. Tím se zahájí test a na přípravku se rozsvítí modrá LED. 8. Vyčkat na dokončení testu. Délka testu je dána nahranou corridor funkcí. 9. Správné otestování je potvrzeno rozsvícením zelené diody na přípravku. V případě rozsvícení rudé diody je test NOK. 10. Po dokončení testu stisknout červené tlačítko. 11. Pro otestování dalšího svítidla postupovat od bodu 3. tohoto postupu.

ZPĚT

2. TABULKA VARIANT | provádí/funkce: | Zkušební technik

Program č. 1 | FIN:0.7s, RON:120s/100%, FOUT:32s, ABL:10%, SOFF:/
Program č. 2 | FIN:0.7s, RON:150s/100%, FOUT:30s, ABL:10%, SOFF:/
Program č. 3 | FIN:0.7s, RON:150s/72%, FOUT:30s, ABL:10%, SOFF:/
Program č. 4 | FIN:0.7s, RON:150s/100%, FOUT:32s, ABL:10%, SOFF:/
Program č. 5 | FIN:0.7s, RON:120s/100%, FOUT:30s, ABL:10%, SOFF:/
Program č. 6 | FIN:0.7s, RON:300s/100%, FOUT:32s, ABL:30%, SOFF:/
Program č. 7 | FIN:0.7s, RON:0s/100%, FOUT:180s, ABL:20%, SOFF:1200s
Program č. 8 | FIN:2s, RON:600s/100%, FOUT:120s, ABL:10%, SOFF:600s
Program č. 9 | FIN:2s, RON:300s/100%, FOUT:120s, ABL:5%, SOFF:/
Program č. 10 | FIN:0.7s, RON:300s/100%, FOUT:32s, ABL:10%, SOFF:/
Program č. 11 | FIN:0.7s, RON:0s/100%, FOUT:16s, ABL:10%, SOFF:180s
Program č. 12 | FIN:0.7s, RON:270s/100%, FOUT:32s, ABL:10%, SOFF:600s
Program č. 13 | FIN:0.7s, RON:30s/100%, FOUT:32s, ABL:20%, SOFF:/

ZPĚT

Jen pro vnitřní potřebu TREVOS a.s. Úložiště : C:\TREVOS\02_Vyrobni_usek\04_Montaze 5260\01_Montaze_Technologicke_postupy\65 - EVELUX\EVELUX S 24-XX-XXX.docx

TP 170009970009901 TREVOS a.s. Datum tisku : 10.11.2022 Revize : A REŽIM DOKUMENTU SE SCHVÁLENÍM strana : 5 z 8

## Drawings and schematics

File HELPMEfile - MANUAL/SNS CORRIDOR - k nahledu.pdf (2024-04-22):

# WIRING DIAGRAM OF LUMINAIRE

# SNS CORRIDOR

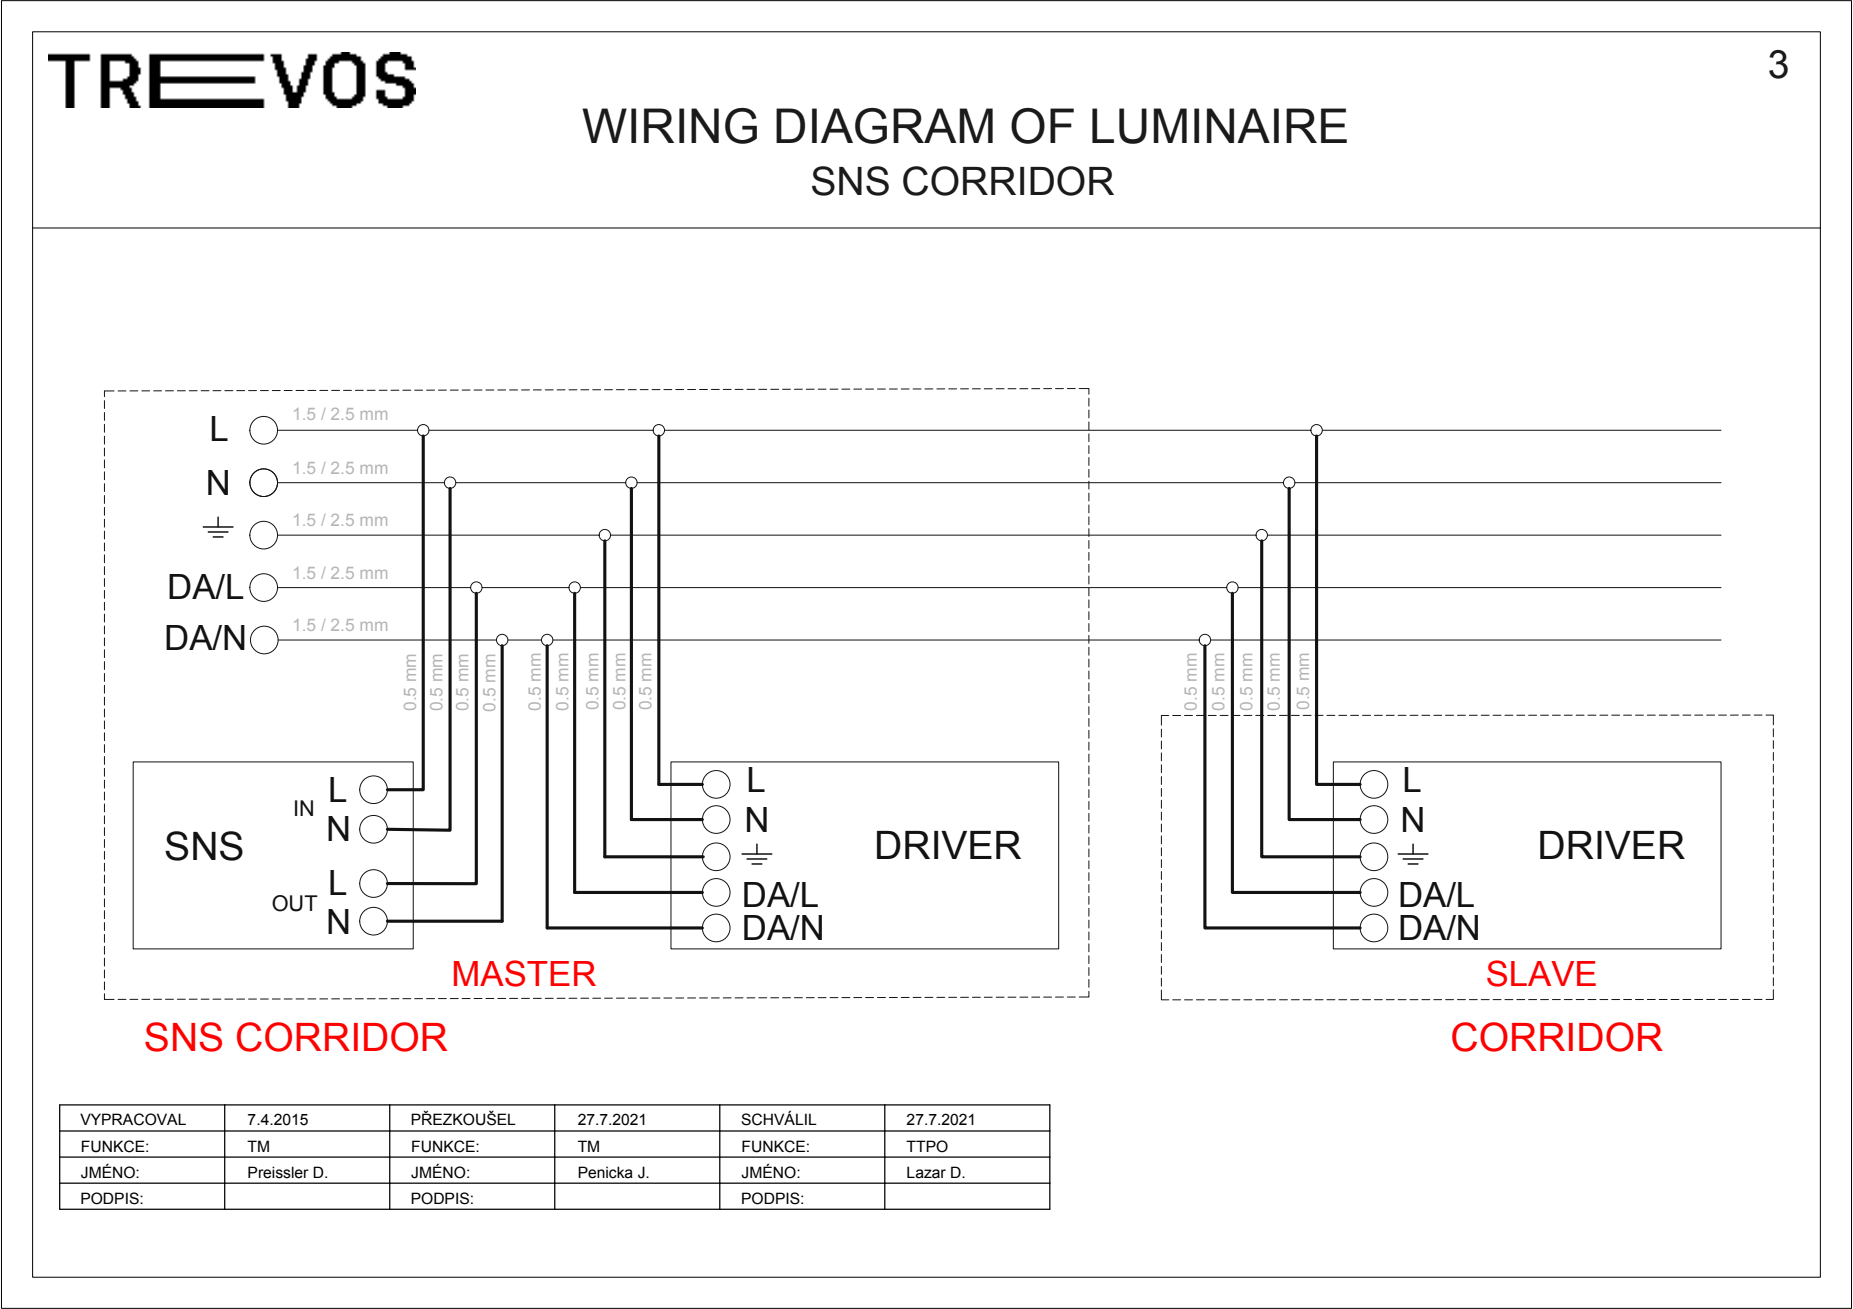
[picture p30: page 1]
SNS; DRIVER; MASTER; SLAVE; OUT; CORRIDOR; SNS CORRIDOR

VYPRACOVAL | 7.4.2015 | PEZKOUEL | 27. 7.2021 | SCHVÁLIL | 27. 7.2021

FUNKCE: | TM | FUNKCE: | TM | FUNKCE: | TTPO

JMÉNO: | Preissler D. | JMÉNO: | Penicka J. | JMÉNO: | Lazar D.

PODPIS: | | PODPIS: | | PODPIS:

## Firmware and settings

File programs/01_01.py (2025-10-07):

from machine import Pin, I2C
from os import listdir
from SH1106 import SH1106_I2C
from utime import sleep
from BH1750 import BH1750
from neopixel import Neopixel
import DS1307, _thread, micropython
import config

v = config.v
print(f"version {v}")
rotate_display = config.display_rotation

program = "1"
version = f" - FIN:0.7s, RON:120s/100%, FOUT:32s, ABL:10%, SOFF:/"

print(f"box # {config.box_version}")

"""
LUX CORRIDOR meter

The relay waits until it gets stable reading of OFF luminaire. And then start the cycle of measurement and data-write phase.
"""
DEBUG = False #If TRUE, program shows extra data in shell

FADE1 = 0.7
HOLD1 = 120
LEVEL1 = 100
FADE2 = 32
HOLD2 = 600 #even when the CORRIDOR won't stop it needs time to know how long to measure
LEVEL2 = 10
FADE3 = 0
HOLD3 = 0
LEVEL3 = 0
INFINITE = True # if TRUE > HOLD2 INDEFINITELY or HOLD3 INDEFINITELY | FALSE if exact by the times stated above

TOLERANCE = 0.10 #tolerance porovnani dat 10%
TOL_LUX = 0.02 #tolerance zmeny hodnoty v namerenych lumenech 2%
cas_bezi = 0

# display update and read data time 0.1 works well for now
update_time = 0.42
pix_val = 0.5 # variable for PIXELS value - set between 0.35 - 3

#program_end = False
program_result = "nevyhodnocen/program ukončen předčasně"
OK = True   # PROGRAM final verdict | False = NOK


i2c = I2C(0, scl=Pin(17), sda=Pin(16), freq=400000)

# display
width = 128
height = 64
oled = SH1106_I2C(width=width, height=height, i2c=i2c, rotate=rotate_display) #rotate used to be 180, now testing 0
oled.fill(0)

# light meter module
light = BH1750(i2c)

# RealTimeClock module
ds = DS1307.DS1307(i2c)

# relays
relay = Pin(21, Pin.OUT)
relay02 = Pin(22, Pin.OUT)
relay.value(1)
relay02.value(1)

# strip of 1 chips, state machine 0, GPIO 28(pin34), RGB mode
n_leds = 1
pixels = Neopixel(n_leds, 0, 28, "GRB")

# buttons
button_ok = Pin(20, Pin.IN, Pin.PULL_DOWN)
button_up = Pin(19, Pin.IN, Pin.PULL_DOWN)
button_down = Pin(18, Pin.IN, Pin.PULL_DOWN)

# control LED
LED = Pin(25, Pin.OUT)
LED.value(0)

# sets MOOD LED to READY
pixels.fill((25*pix_val, 10*pix_val, 0)) # ORANGE
pixels.show()

#enable oscillator
#ds.halt(FALSE)

# sets actual time year/month/day/DOW(starts with sunday=0)/hour/minute/second/subseconds
# now = (2022, 5, 30, 1, 8, 57, 30, 0)
# ds.datetime(now)

time_reserve = 1

if INFINITE == True:
    time_reserve = 1.15
    trvani_s_rezervou = (5 + FADE1 + HOLD1 + FADE2 + HOLD2 + FADE3 + HOLD3) * time_reserve
else:
    time_reserve = 1.08
    trvani_s_rezervou = (5 + FADE1 + HOLD1 + FADE2 + HOLD2 + FADE3 + HOLD3) * 1.08

if DEBUG == True:
    print(f"{trvani_s_rezervou} trvani_s_rezervou")

def format_seconds_to_hhmmss(seconds):
    hours = seconds // (60*60)
    seconds %= (60*60)
    minutes = seconds // 60
    seconds %= 60
    return "%02i:%02i:%02i" % (hours, minutes, seconds)

celkovy_cas_rezerva = format_seconds_to_hhmmss(trvani_s_rezervou)

def get_time():
    time_list = ds.datetime()
    print(f"Time is {time_list[4]}:{time_list[5]}:{time_list[6]} {time_list[0]}-{time_list[1]}-{time_list[2]}")

if DEBUG == True:
    get_time()

def get_seconds():
    allseconds = (counter_s + (counter_m * 60) + (counter_h * 60 * 60))
    return allseconds

# set variables for measurement and comparison
"""
Variables for final written data
Val0 - Val4 = lux
Tim0 - Tim6 = sec
Per1 and Per2 = %
Fad1, Fad2 and Fad3 = sec
Hol1, Hol2, and Hol3 = sec
"""
Val0 = "x"
Val1 = "x"
Val2 = "x"
Val3 = "x"
Val4 = "x"
Tim0 = "x"
Tim1 = "x"
Tim2 = "x"
Tim3 = "x"
Tim4 = "x"
Tim5 = "x"
Tim6 = "x"
# calculated from the values Val and Tim
Per1 = "x"
Per2 = "x"
Fad1 = "x"
Fad2 = "x"
Fad3 = "x"
Hol1 = "x"
Hol2 = "x"
Hol3 = "x"

phase = "warm up"
phase2 = ""

# time counters
counter_s = 0
counter_m = 0
counter_h = 0

# data LOGGING counter
counter_log = 1

# for last 5 values to compare if stabilised
lux_list = [0, 0, 0, 0, 0]
lux_value = [False, False, False, False, False]

stable_boolean = False

# waiting phase
while True:
    if button_ok.value() == 1:
        break
    LED.toggle()
    oled.fill(0)
    lux = light.luminance(BH1750.CONT_HIRES_1)
    lux = str(round(lux, 0))
    oled.text(lux + " lx", 0, 0)
    oled.text("PRESS START", 15, 18)
    oled.text("Delka testu:", 0, 36)
    oled.text(celkovy_cas_rezerva, 0, 48)
    oled.show()
    sleep(0.18)

# sets MOOD LED to MEASUREMENT STARTS
pixels.fill((0, 0, 15*pix_val)) # BLUE
pixels.show()

sleep(1)

# measurement phase
time_list = ds.datetime()

# corrects file name time and date to format 2022-07-05 from 2022-7-5 etc
for i in range (0,6):
    time_list = list(time_list)

    if time_list[i] <= 9:
        time_list[i] = (f"0{time_list[i]}")
    time_list = tuple(time_list)

test_file_name = (f"/mereni/B{config.box_version}__{time_list[0]}-{time_list[1]}-{time_list[2]}_{time_list[4]}-{time_list[5]}-{time_list[6]}__p{program}v{v}.txt")
file = open(test_file_name, "w")
file.write(f"Program {program} started {time_list[4]}:{time_list[5]}:{time_list[6]} {time_list[0]}-{time_list[1]}-{time_list[2]}" + "\n" + f"version: v{v}-{version}" + "\n")
file.write("\n" + f"Parameters:" + "\n" + f"Fade {FADE1}s, Hold {HOLD1}s at {LEVEL1}%" + "\n")
file.write(f"fade {FADE2}s, hold {HOLD2}s at {LEVEL2}%" + "\n")
file.write(f"fade {FADE3}s, hold {HOLD3}s at {LEVEL3}%" + "\n")

if INFINITE == True:
    file.write(f"Driver never shuts down to 0% but measurement runs for: {celkovy_cas_rezerva}" + "\n")
elif INFINITE == False:
    file.write(f"Driver shuts down to 0% and measures: {celkovy_cas_rezerva}" + "\n")
file.write("\n")
file.flush()


time_start = [time_list[4], time_list[5], time_list[6]]
time_actual = [time_list[4], time_list[5], time_list[6]]

sec_to_measure = time_actual[2]



while True:
    if button_ok.value() == 1:
        file.write("Shut down by BUTTON press" + "\n")
        break

    # LEDs to see whether it FROZE or NOT
    LED.toggle()
    pixels.fill((3*pix_val, 3*pix_val, 3*pix_val)) # WHITE
    pixels.show()

    # updates time list
    time_list = ds.datetime()
    time_actual = [time_list[4], time_list[5], time_list[6]]

    # TIME counters - updates 1 second counter which dictates if it is ready to read and write data
    if time_actual[2] > sec_to_measure or time_actual[2] < sec_to_measure:
        sec_to_measure = time_actual[2] # updates
        counter_log = 1 # calls datalogging
        counter_s += 1

    if counter_s >= 60:
        counter_s = 0
        counter_m += 1

    if counter_m >= 60:
        counter_m = 0
        counter_h += 1


    # READS lumen value
    lux = light.luminance(BH1750.CONT_HIRES_1)
    if DEBUG == True:
        print(f"{lux} lux type {type(lux)}")
    lux = str(round(lux, 1))  # round to whole numbers
    oled.fill(0)

    # DISPLAY update
    oled.text(str(counter_h) + ":" + str(counter_m) + ":" + str(counter_s) + f"/{celkovy_cas_rezerva}", 0, 0)
    oled.text(lux + " lx", 0, 12)
    oled.text("Phase: ", 0, 24)
    oled.text(phase, 0, 36)
    oled.text(phase2, 0, 48)
    oled.show()

    # DATA LOGGER
    # checks whether it is needed to write and compare LUX data
    if counter_log == 1:

        counter_log = 0
        lux_list.insert(0, lux)
        if len(lux_list) > 5:
            lux_list.pop()

        lx_valmin = (float(lux_list[1])) * (1 - TOL_LUX)
        lx_valmax = (float(lux_list[1])) * (1 + TOL_LUX)

        if float(lux) >= lx_valmin and float(lux) <= lx_valmax:  # and float(lux) >= lx_val095 or float(lux) <= lx_val105
            lux_value.insert(0, True)
            stable_boolean = True
        else:
            lux_value.insert(0, False)
            stable_boolean = False

    if len(lux_value) > 5:
        lux_value.pop()
        if DEBUG == True:
            print(f"{lux_list} lux_list")
            print(f"{lux_value} lux_value")
    stable = all(i for i in lux_value)

# OPERATIVE phase - for better imagining of the process check /blueprints/scheme.jpg

    if Val0 == "x" and stable == True:
        relay.value(0)
        sleep(5)
        relay02.value(0)
        sleep(3)
        Val0 = lux
        Tim0 = get_seconds() - 0  # play with this number in real situations | 0 sec for this is where all other starts
        stable = False  # this condition and the line above IS enough to catch the OFF ON transition, so it does not evaluate STABLE = TRUE immediately
        file.write("Measurement:" + "\n")
        file.write("Stable at: " + str(Val0) + "lx\n")
        relay02.value(1)

    if Val1 == "x" and stable == True:
        Val1 = lux
        Tim1 = get_seconds() - 5
        if float(Val1) < 1.0:
            #button_pressed = True
            program_result = "Val1 nemuze byt nula"
            file.write("Val1 nemuze byt nula" + "\n")
            break

        phase = "Operative:"
        phase2 = "Tim 1 - HOLD"

# Standby 1
    if Tim1 != "x" and Tim2 == "x" and stable_boolean == False:
        Tim2 = get_seconds()
        phase = "StandBy 1:"
        phase2 = "Tim 2 - FADE"
        Hol1 = Tim2 - Tim1
        Fad1 = Tim1 - Tim0

        if Fad1 <= 1 and FADE1 <= 1:
            file.write("OK")
        elif Fad1 <= (10 * FADE1):
            file.write(f"OK-ish")
        else:
            if float(FADE1) <= Fad1 + (Fad1 * TOLERANCE) and float(FADE1) >= Fad1 - (Fad1 * TOLERANCE):
                file.write("OK")
            else:
                file.write("NOK")
                OK = False

        file.write(" - Fade time 1: " + str(Fad1) + "s\n")

        if float(HOLD1) <= Hol1 + (Hol1 * TOLERANCE) and float(HOLD1) >= Hol1 - (Hol1 * TOLERANCE):
            file.write("OK")
        else:
            file.write("NOK")
            OK = False

        file.write(" - Hold time 1: " + str(Hol1) + "s at value: " + str(Val1) + "lx (100%)\n")
        file.flush()

    if Tim1 != "x" and Tim2 != "x" and Tim3 == "x" and stable == True:
        Val2 = lux
        Tim3 = get_seconds()
        Tim3 -= 5
        phase2 = "Tim 3 - HOLD"
        Fad2 = Tim3 - Tim2
        Per1 = round((float(Val2) / float(Val1)) * 100, 1)

        if float(Val2) == 0.0:
            #button_pressed = True #ENDS CYCLE
            program_result = "END at Tim3, Val2 = 0"
            if LEVEL2 == 0.0:
#                OK = True
                file.write(" - Fade time 2: " + str(Fad2) + "s\n")
                file.write(f"OK - Val2: {str(Val2)} equals {str(LEVEL2)}\n")
                file.flush()
            break
        elif float(FADE2) <= Fad2 + (Fad2 * TOLERANCE) and float(FADE2) >= Fad2 - (Fad2 * TOLERANCE):
            file.write("OK")
        else:
            file.write("NOK")
            OK = False
            break

        file.write(" - Fade time 2: " + str(Fad2) + "s\n")

        if float(LEVEL2) <= Per1 + (Per1 * (1 * TOLERANCE)) and float(LEVEL2) >= Per1 - (Per1 * (2 * TOLERANCE)):
            file.write("OK")
        elif float(LEVEL2) >= Per1 - (Per1 * (4 * TOLERANCE)):
            file.write("OKish")
        else:
            file.write("NOK")
            OK = False

        file.write(" - level 2: " + str(Per1) + "%" + "\n")
        file.flush()

# Standby 2
    if Tim3 != "x" and Tim4 == "x" and stable_boolean == False:
        Tim4 = get_seconds()
        phase = "StandBy 2:"
        phase2 = "Tim 4 - FADE"
        Hol2 = Tim4 - Tim3
        if float(HOLD2) <= Hol2 + (Hol2 * TOLERANCE) and float(HOLD2) >= Hol2 - (Hol2 * TOLERANCE):
            file.write("OK")
        else:
            file.write("NOK")
            OK = False
    elif Tim3 != "x" and Tim4 == "x" and get_seconds() >= (FADE1 + HOLD1 + FADE2 + HOLD2) and INFINITE == True:
        Tim4 = get_seconds()
        phase = "StandBy 2:"
        phase2 ="End is near"
        Hol2 = Tim4 - Tim3
        if float(HOLD2) <= Hol2 + (Hol2 * TOLERANCE) and float(HOLD2) >= Hol2 - (Hol2 * TOLERANCE):
            file.write("OK")
        else:
            file.write("NOK")
            OK = False

        file.write(" - hold time 2: " + str(Hol2) + "s at value: " + str(Val2) + "lx " + "at " + str(Per1) + "%" + "\n")
        file.flush()


    if Tim4 != "x" and Tim5 == "x" and stable == True and INFINITE == False:
        Val3 = lux
        Tim5 = get_seconds()
        Tim5 -= 5
        Per2 = round(float(Val3) / float(Val1) * 100, 1)
        phase2 = "Tim 5 - HOLD"
        Fad3 = Tim5 - Tim4

        if float(FADE3) <= Fad3 + (Fad3 * TOLERANCE) and float(FADE3) >= Fad3 - (Fad3 * TOLERANCE):
            file.write("OK")
        elif Fad3 <= (10 * FADE3):
            file.write("OK-ish")
        else:
            file.write("NOK")
            OK = False

        file.write("- fade time 3: " + str(Fad3) + "s\n")

        if float(LEVEL3) <= Per2 + (Per2 * TOLERANCE) and float(LEVEL3) >= Per2 - (Per2 * TOLERANCE):
            file.write("OK")
        else:
            file.write("NOK")
            OK = False

        file.write(f"- to level 3: {Per2}%\n")
        file.flush()

    if Tim6 == "x" and Tim5 != "x" and stable_boolean == False:
        Tim6 = get_seconds()
        Val4 = lux
        phase2 = "Tim 6 - END"
        Hol3 = Tim6 - Tim5

        if float(HOLD3) <= Hol3 + (Hol3 * TOLERANCE) and float(HOLD3) >= Hol3 - (Hol3 * TOLERANCE):
            file.write("OK")
        else:
            file.write("NOK")
            OK = False

        file.write("- hold time 3: " + str(Hol3) + "s at value: " + str(Val3) + "lx " + "\n")
        file.write("Final lx value: " + str(Val4) + "\n")
        file.flush()
        #button_pressed = True
        break

    #AUTOMATIC END if measuring too long TIME+10%
    cas_bezi = float(get_seconds())
    cas_celeho_testu = float(trvani_s_rezervou) * 1.0

    if DEBUG == True:
        print(f"{cas_bezi}/{cas_celeho_testu}")

    if cas_bezi >= cas_celeho_testu:
        print("piskej KONEC KURVA!")

        if DEBUG == True:
            print(f"Per1 {Per1}")
            print(f"Per2 {Per2}")

        if INFINITE == True:
            if Per2 == "x" or Per2 > 1:
                Per2X = True
            if float(Per1) > 1 and Per2X == True:
                file.write(f"OK - Světlo svítilo dál, ukončeno automaticky po definovaném čase\n")
            else:
                file.write(f"NOK - Světlo zhaslo, ukončeno zhasnutím\n")
                OK = False
        break


    if DEBUG == True:
        micropython.mem_info()

    pixels.fill((0, 0, 15*pix_val))  # BLUE
    pixels.show()
    sleep(update_time)

"""Result comparison"""
if Val0 == "x" or Val1 == "x" or Val2 == "x":
    OK = False

oled.fill(0)
if OK == True:
    oled.text("- OK -", 0, 24)
    program_result = "OK"
    pixels.fill((0, 80 * pix_val, 0))
    pixels.show()
else:
    oled.text("! - NOK - !", 0, 24)
    program_result = "NOK"
    pixels.fill((80 * pix_val, 0, 0))
    pixels.show()
oled.show()

file.write("\n" + "Result:" + "Measurement " + program_result + "\n")

relay.value(1) #shuts off luminaire
relay02.value(1) #shuts off phase from Relay02
LED.value(0) #shuts off control LED on RPiPico
file.close()

# WAIT phase for button click before jumping back to the menu
while True:
    if button_ok.value() == 1:
        break
    if button_up.value() == 1 and button_down.value() == 1:
        oled.fill(0)
        oled.text(f"{program}-v{v} - {program_result}", 0, 0)
        oled.text(f"{Val1} lm", 0, 9)
        oled.text(f"{Hol1}/{HOLD1} hold", 0, 18)
        oled.text(f"{Fad2}/{FADE2} fade", 0, 27)
        oled.text(f"{Per1}/{LEVEL2} %", 0, 36)
        oled.text(f"{Hol2}/{HOLD2} hold", 0, 45)
        oled.text(f"", 0, 54)
        oled.show()

# re-sets MOOD LED to END
pixels.fill((0, 0, 0))
pixels.show()
sleep(0.75)

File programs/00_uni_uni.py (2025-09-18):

from machine import Pin, I2C
from BH1750 import BH1750
from SH1106 import SH1106_I2C
from neopixel import Neopixel
import DS1307
import utime

v = "1.02 uni"
"""
LUX meter

UNIVERSAL measurement - writes data every X sec!! (1, 5, 10, 30, 60, 600, 3600)
You can set timed OFF of measurement after "never", 1, 2, 4, 8, 12, 24 or 168 hours. 

There is a graph of last 30 values on the display

RELAY - Turns on at the start of the measurement
RELAY02 - push UP+DOWN to turn on momentarily
LED blinks while reading value - green while value changes, blue if it is considered the light source a stable one
Display(i2c) 128x64
RTC module
3x buttons START/STOP, UP, DOWN
1x reset
+ GRAPH of 30 last values

Přidat verzi: program name: uni-cycle? Pun intended. Or add it at choosing the times of OFF timer.
Nastavit délku doby měření (ON-stykače) v hodinách, když 0, tak bez limitu a ostatní nastavování přeskočit.
Nastavit délku doby měření v (OFF-stykače) v hodinách, měření stále bude zapisovat
Nastavit počet cyklů. 

Add version with timer that counts up the time and gives data-over time and shows TIME UP after end of testing
EMERGENCY - how long battery lasts. Possibly when the lumen drop below 5% of what it was?

rework the time tokens, to consider RTC unit and compare real-time to frequency, not as a tokens.
rework time with W module - so it can grab actual time of internet

GRAPH turn on and turn off? Variable?
"""

DATA_SAVE = True
stable_checker = 3 #values
TIMED_END = True
stable_tolerance = 25
#turns L3 5 times ON and OFF in 2.5 seconds
reset_corridor = False

i2c = I2C(0, scl=Pin(17), sda=Pin(16), freq=400000)

# display
width = 128
height = 64
oled = SH1106_I2C(width=width, height=height, i2c=i2c, rotate=0)
oled.fill(0)

# light meter module
light = BH1750(i2c)

# RealTimeClock module
ds = DS1307.DS1307(i2c)

# relays
relay = Pin(21, Pin.OUT)
relay02 = Pin(22, Pin.OUT)
relay.value(1)
relay02.value(1)

# control LED
LED = Pin(25, Pin.OUT)
LED.value(0)

# strip of 1 chips, state machine 0, GPIO 28(pin34), RGB mode
n_leds = 1
pixels = Neopixel(n_leds, 0, 28, "GRB")
# sets MOOD LED to READY
pixels.fill((25, 10, 0))
pixels.show()

# buttons
button_ok = Pin(20, Pin.IN, Pin.PULL_DOWN)
button_up = Pin(19, Pin.IN, Pin.PULL_DOWN)
button_down = Pin(18, Pin.IN, Pin.PULL_DOWN)

# enable CLOCK oscillator (for starting a new machine)
# ds.halt(FALSE)

# for setting the TIME and EDITS
# sets actual time year/month/day/DOW(starts with sunday=0)/hour/minute/second/subseconds
# print(ds.datetime())
# now = (2023, 1, 26, 4, 7, 50, 0, 0)
# ds.datetime(now)


def get_time():
    time_list = ds.datetime()
    print(f"Time is {time_list[4]}:{time_list[5]}:{time_list[6]} {time_list[0]}-{time_list[1]}-{time_list[2]}")

get_time()

def lux():
    lux = light.luminance(BH1750.CONT_HIRES_1)
    lux = int(round(lux, 0))
    lm = lux
    if lm <= 1:
        lm = 1
    return lm


freq_list = (1, 5, 10, 30, 60, 600, 3600)
frequency = freq_list[0]
selection = 0

#selection of SAMPLING frequency
while True:
    if button_ok.value() == 1:
        break
    if button_up.value() == 1:
        if selection >= 6: #zkopirovat tohle do MAIN.py menu
            continue
        else:
            selection += 1
            frequency = freq_list[selection]
    if button_down.value() == 1:
        if selection <= 0:
            continue
        else:
            selection -= 1
            frequency = freq_list[selection]

    LED.toggle()
    oled.fill(0)
    lm = lux()

    oled.text(f"sampling {frequency}s", 0, 0)
    oled.text(f"...", 0, 12)
    oled.text(str(lm) + " lx", 0, 24)
    oled.text("PRESS START", 15, 36)
    oled.show()
    utime.sleep(0.14)

utime.sleep(1)


timeOFF_list = (0, 1, 2, 4, 8, 12, 24, 168)
timeOFF = timeOFF_list[0]
selectionOFF = 0

# selection of OFF TIME
while True:
    if button_ok.value() == 1:
        break
    if button_up.value() == 1:
        if selectionOFF >= len(timeOFF_list)-1:
            continue
        else:
            selectionOFF += 1
            timeOFF = timeOFF_list[selectionOFF]
    if button_down.value() == 1:
        if selectionOFF <= 0:
            continue
        else:
            selectionOFF -= 1
            timeOFF = timeOFF_list[selectionOFF]

    LED.toggle()
    oled.fill(0)
    lm = lux()

    oled.text(f"sampling {frequency}s", 0, 0)
    if timeOFF == 0:
        oled.text(f"Nevypne..", 0,12)
    else:
        oled.text(f"Vypne po:{timeOFF}h", 0, 12)
    oled.text(str(lm) + " lx", 0, 24)
    oled.text("PRESS START", 15, 36)
    oled.show()
    utime.sleep(0.14)

if timeOFF == 0:
    TIMED_END = False

# sets MOOD LED to MEASUREMENT STARTS
pixels.fill((0, 0, 10))
pixels.show()
utime.sleep(1)

# measurement phase
time_list = ds.datetime()

# corrects file name time and date to format 2022-07-05 from 2022-7-5 etc
for i in range(0, 6):
    time_list = list(time_list)

    if time_list[i] <= 9:
        time_list[i] = f"0{time_list[i]}"
    time_list = tuple(time_list)

test_file_name = (
    f"/mereni/{time_list[0]}-{time_list[1]}-{time_list[2]}_{time_list[4]}-{time_list[5]}-{time_list[6]}-{v}-freq{frequency}s.txt")
file = open(test_file_name, "w")
file.write(
    f"Program started {time_list[4]}:{time_list[5]}:{time_list[6]} {time_list[0]}-{time_list[1]}-{time_list[2]} v{v}_freq_{frequency}s with time OFF set to {timeOFF}h and {stable_tolerance} lm tolerance" + "\n")
file.flush()

# display update and read data time 0.1 works well for now
update_time = 0.02

time_start = [time_list[4], time_list[5], time_list[6]]
time_actual = [time_list[4], time_list[5], time_list[6]]

sec_to_measure = time_actual[2]

# time counters
counter_s = 0
counter_m = 0
counter_h = 0

# data LOGGING counter
counter_log = frequency - 1

graph_list = []
graph_max = 2
oled.fill(0)

data_saver = []
save_data_ph1 = stable_checker - 1
save_data_ph2 = stable_checker - 1
stable_phase1 = False
stable_phase2 = False
lx_ph1_compare = "x"
pix_green = (0, 25, 0)
pix_blue = (0, 0, 25)
pix_red = (10, 0, 0)

#JUST TO RESET CORRIDOR
while reset_corridor == True:
    relay.value(0)
    utime.sleep(2)
    for i in range(10):
        relay02.toggle()
        utime.sleep(0.25)
    break
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

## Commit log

2022-08-15 updates added DEBUG variable - last state crashed a lot around 50 - 65 sec. Now it seemes ok.
    [02_REG_01_x.py, main.py]
2022-08-18 updates and bug smashing
    [00_uni_uni.py, 01_uni.py, 02_REG_01.py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]
2022-08-31 v1.31 updates and bug smashing
    [02_REG_01.py]
2022-11-09 v1.32 updates and bug smashing
    [00_uni_uni.py, 01_01.py, 01_02.py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]
2022-12-06 v2.4 updates and bug smashing deleted 2nd thread for better stability
    [00_uni_uni.py, 01_01.py, 01_02.py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]
2022-12-15 v2.41 updates and bug smashing deleted 2nd thread for better stability and life quality uni_uni now has timer to turn off in certain time of measurement and data saver
    [00_uni_uni.py, main.py]
2023-02-28 v2.45 uni_uni updates to data_saver feature update to manual
    [BOX - LED COVER.stl, WINDOW V0.2.stl, WINDOW-door V0.2.stl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]
2023-05-09 v2.46 uni_uni updates to data_saver feature change to SH1106 display
    [components.xlsx]
2023-05-09 updates
    updates
    [new project.csv, new project.kicad_pcb, new project.kicad_sch]
2024-03-08 update to 2.6 version of corridor programs
    minor improvements to none in uni-uni
    [2022_04_26_LUX METER BOX SNS case V.XYZ.blend, basic box - buttons and all.blend, components.xlsx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]
2024-03-28 update to 2.61 version of corridor for some programs
    [basic box - buttons and all.blend]
2024-04-09 update to 2.62 version of corridor for some programs #1, #15-#21 are updated.
    Prepared for display rotation of 0° instead of 180°.
    [BOX - LED COVER.stl, basic box - buttons and all.blend]
2024-04-15 update to 2.62 version of corridor for some programs #1-21 updated for slow T-LED drivers
2024-04-19 Commit before merging
    [2022_04_26_LUX METER BOX SNS case V.XYZ.stl, 2022_04_26_LUX METER BOX SNS case V.XYZ01.stl, 2022_04_26_LUX METER BOX.blend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]
2024-06-28 update to 2.62 version of corridor for some programs #1-21 updated for slow T-LED drivers
    Also, preparation for config.py file, that would hold few of the data together for quicker updates and distinction of corridor boxes, for now, there are 2 and 1 "unit" on my table
    [programy - priprava.xlsx]
2024-09-13 update to 2.62 version of corridor for some programs #1-21 updated for slow T-LED drivers
    Also, preparation for config.py file, that would hold few of the data together for quicker updates and distinction of corridor boxes, for now, there are 2 and extra 1 "unit" on my table
    [tabulka programu.xlsx]
2024-11-22 update to 3.0 version with config file. Now only few files use it though.
    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
    [tabulka programu.xlsx]
2024-12-09 update to 3.0 version with config file. Now only few files use it though.
    Edited export file name for better readibility (now just for program number 29).
    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
    [tabulka programu.xlsx]
